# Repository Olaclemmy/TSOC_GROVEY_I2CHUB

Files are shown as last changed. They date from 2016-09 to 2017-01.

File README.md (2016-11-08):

# TSOC_GROVEY_I2CHUB
**TSOC_GROVEY_I2CHUB** is a four(4) port I2C Hub/Switch board, an Embedded Module for thingSoC.

The **TSOC_GROVEY_I2CHUB** can operate at either 3.3V or 5V, and can also level translate 3.3V processor I2C bus to 5V peripherals when needed.

The **TSOC_GROVEY_I2CHUB** allows you to connect [thingSoC](http://thingsoc.github.io/), [Mikrobus](http://www.mikroe.com/mikrobus/), 
and/or [Grove System](http://www.seeedstudio.com/blog/2016/03/09/tutorial-intro-to-grove-connectors-for-arduinoraspberry-pi-projects/) 
Modules all at the same time, with any processor module.
This gives you maximum flexiblity for sensor and actuator selection, and reuse. 

The thingSoC "Grovey Series" was designed as "Everyday Electronics", a no-frills, low cost, approach to modular embedded product design.
thingSoC boards are similar in size to most break-out-boards (BOBs), but feature a standardized stacking pinout, as well as an I2C metadata store (EEPROM)
to indicate what peripherals are installed.

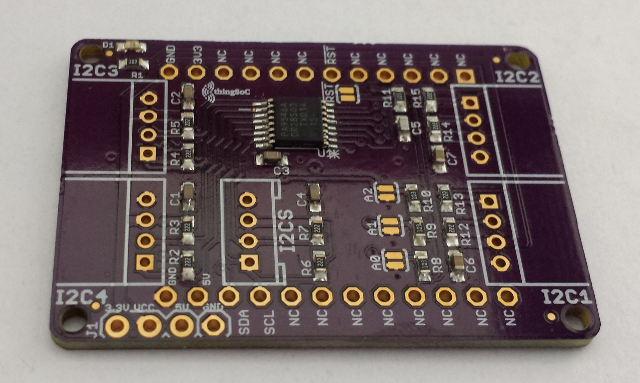
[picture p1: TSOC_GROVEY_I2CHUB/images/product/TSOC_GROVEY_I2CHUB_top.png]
thingSoC GROVEY_I2CHUB
[TSOC_GROVEY_I2CHUB](https://github.com/thingSoC/TSOC_GROVEY_I2CHUB/)

---------------------------------------

In this example, we use the [Grovey_I2CHUB](https://github.com/thingSoC/TSOC_GROVEY_I2CHUB) with the [Teensy3.x](https://www.pjrc.com/teensy/index.html) to support a Grove 16x2 LCD panel.
Since the Grove 16x2 LCD panel is a 5V peripheral, the [Grovey_I2CHUB](https://github.com/thingSoC/TSOC_GROVEY_I2CHUB) performs the voltage level translation
necessary to go from the 3.3V micro-processor to the 5V LCD controller. 

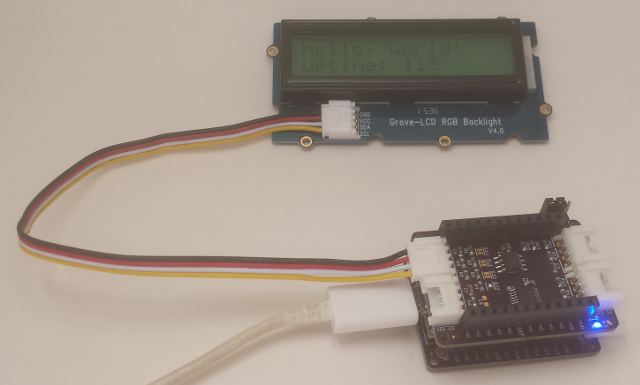
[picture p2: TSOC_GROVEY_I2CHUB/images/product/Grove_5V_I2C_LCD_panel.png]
thingSoC GROVEY_I2CHUB
[TSOC_GROVEY_I2CHUB](https://github.com/thingSoC/TSOC_GROVEY_I2CHUB/)

* [thingSoC Compliant Module](http://www.thingsoc.com)
* [Mikrobus Compatible Module](http://www.mikroe.com/mikrobus/) 
* 5V Nominal Power Input
* 5V or 3.3V Operation
* Supports four (4) separate I2C busses 

---------------------------------------
## Example Uses

* Any time you want to connect four (4) of the same sensor, using the same I2C address, then you need an I2C Hub/Switch.
* Adds four (4) I2C ports to any [thingSoC](http://thingsoc.github.io/), [Mikrobus](http://www.mikroe.com/mikrobus/), 
and/or [Grove System](http://www.seeedstudio.com/blog/2016/03/09/tutorial-intro-to-grove-connectors-for-arduinoraspberry-pi-projects/) peripherals.

---------------------------------------
## 3D Model (Sketchup)

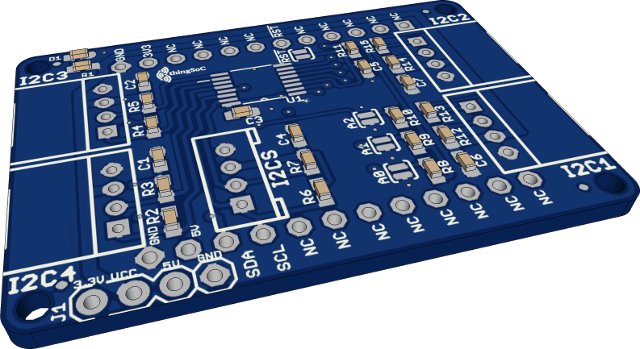
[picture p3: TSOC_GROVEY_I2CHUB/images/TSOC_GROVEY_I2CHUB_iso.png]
thingSoC TSOC_GROVEY_I2CHUB


---------------------------------------
## Project Status

* 09/02/2016 : Revision 2.0 Release for PCB fab

## Revision 2.0 Notes: ##

* Add Ground Strap, remove FM24V10 FRAM, add GROVE I2C Slave connector slot.

## Revision 2.1 Notes: ##

* Remove Ground Strap, it was confusing for power configuration and assembly.
* Prototype testing complete, Production Ready

---------------------------------------

## Documentation Index <a name="documentation_index"/>

[Quick Start Guide](https://github.com/thingSoC/TSOC_GROVEY_I2CHUB/blob/master/TSOC_GROVEY_I2CHUB/docs/QuickStart.md)

[User Guide](https://github.com/thingSoC/TSOC_GROVEY_I2CHUB/blob/master/TSOC_GROVEY_I2CHUB/docs/UserGuide.md)

[Theory of Operation](https://github.com/thingSoC/TSOC_GROVEY_I2CHUB/blob/master/TSOC_GROVEY_I2CHUB/docs/TheoryOfOperation.md)

[thingSoC Organization Website](http://thingSoC.github.io)

[thingSoC FAQ - Frequently Asked Questions](http://thingsoc.github.io/support/faq.html)

---------------------------------------

[  
*thingSoC*](http://thingsoc.github.io)

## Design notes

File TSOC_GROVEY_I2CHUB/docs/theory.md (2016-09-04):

# TSOC_GROVEY_I2CHUB Theory of Operation

***TSOC_GROVEY_I2CHUB** is a self contained, Embedded Wi-Fi Module, with integated Li-Po battery control and charging.

**TSOC_GROVEY_I2CHUB** includes an ESP8266 Wi-Fi module, 
along with an [PCA8575 I/O Expander](http://www.nxp.com/documents/data_sheet/PCA8575.pdf) 
to provide an additional 16 Input/Output pins for the thingSoC Standard Socket,
and a Color RGB LED for USER status, with additonal, individual LEDS for Battery Charger Status and USB Status.

[thingSoC TSOC_GROVEY_I2CHUB  
*TSOC_GROVEY_I2CHUB*](https://github.com/PatternAgents/TSOC_GROVEY_I2CHUB/)

* [Supported by the Arduino IDE](https://www.arduino.cc/) 
* [thingSoC Compliant Module](http://www.thingsoc.com)
* [Mikrobus Compatible Module](http://www.mikroe.com/mikrobus/) 

---------------------------------------

## Theory of Operation <a name="theory_index"/>

The **TSOC_GROVEY_I2CHUB** supports a single "thingSoC" socket with 3.3 Volt Level signaling.

### Page A : USB Connector, Battery Connector and Power Supply<a name="PAGEA"/>

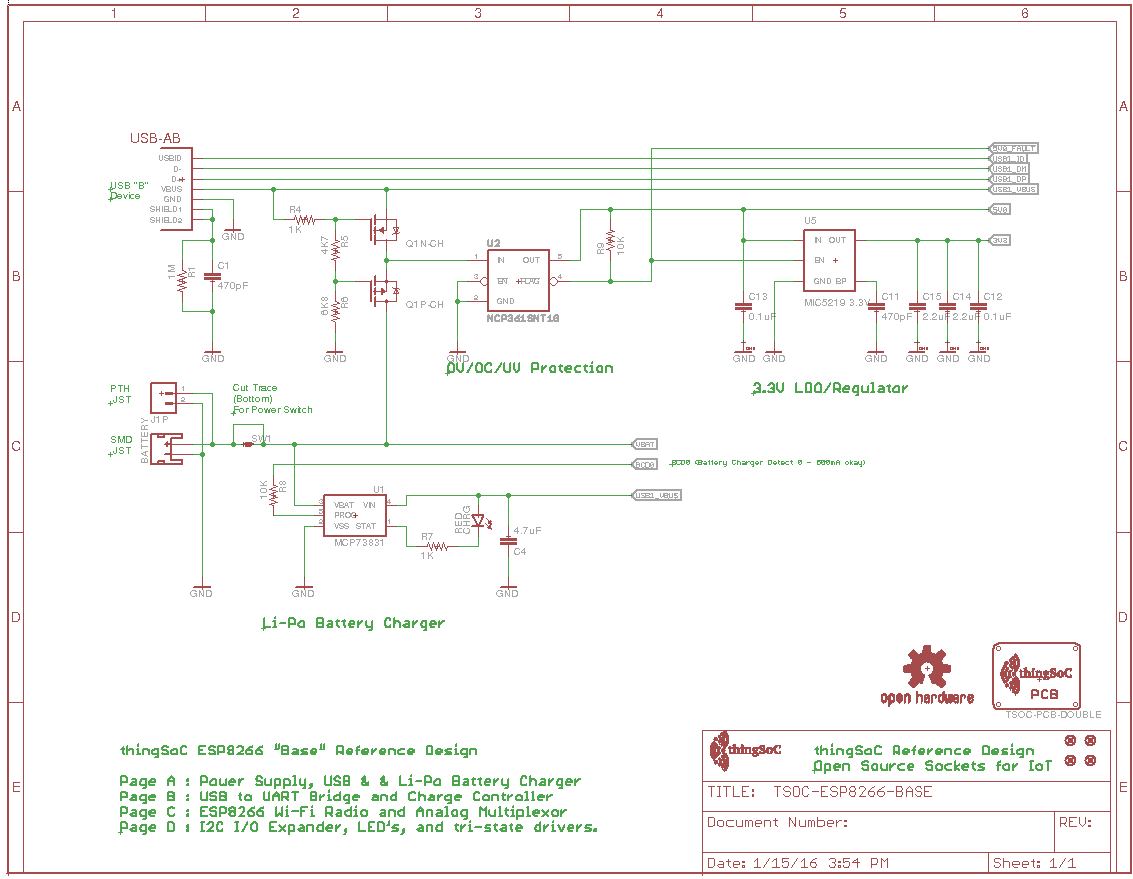
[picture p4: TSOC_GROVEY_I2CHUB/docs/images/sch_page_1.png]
Schematic Page A


Limitations: 

### Page B : USB to UART Bridge Controller <a name="PAGEB"/>

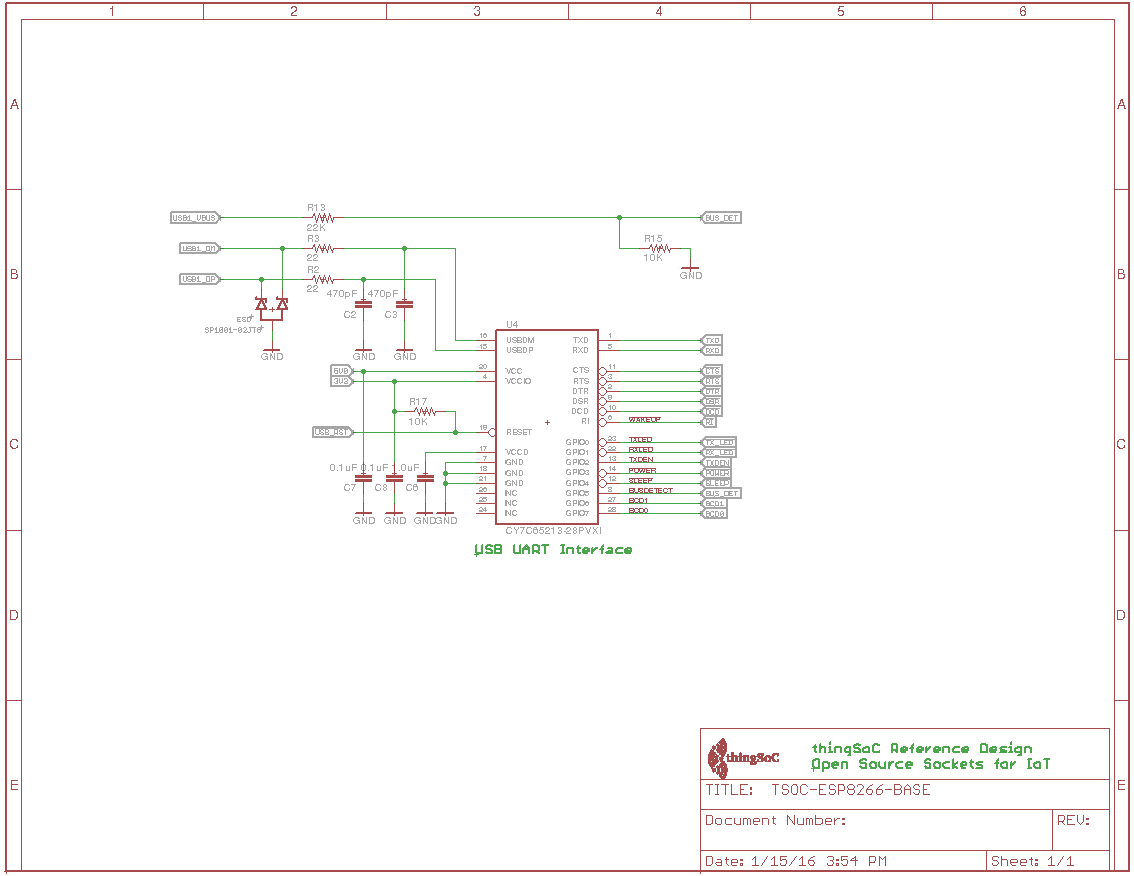
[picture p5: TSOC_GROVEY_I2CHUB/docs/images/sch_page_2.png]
Schematic Page B


### Page C <a name="PAGEC"/>

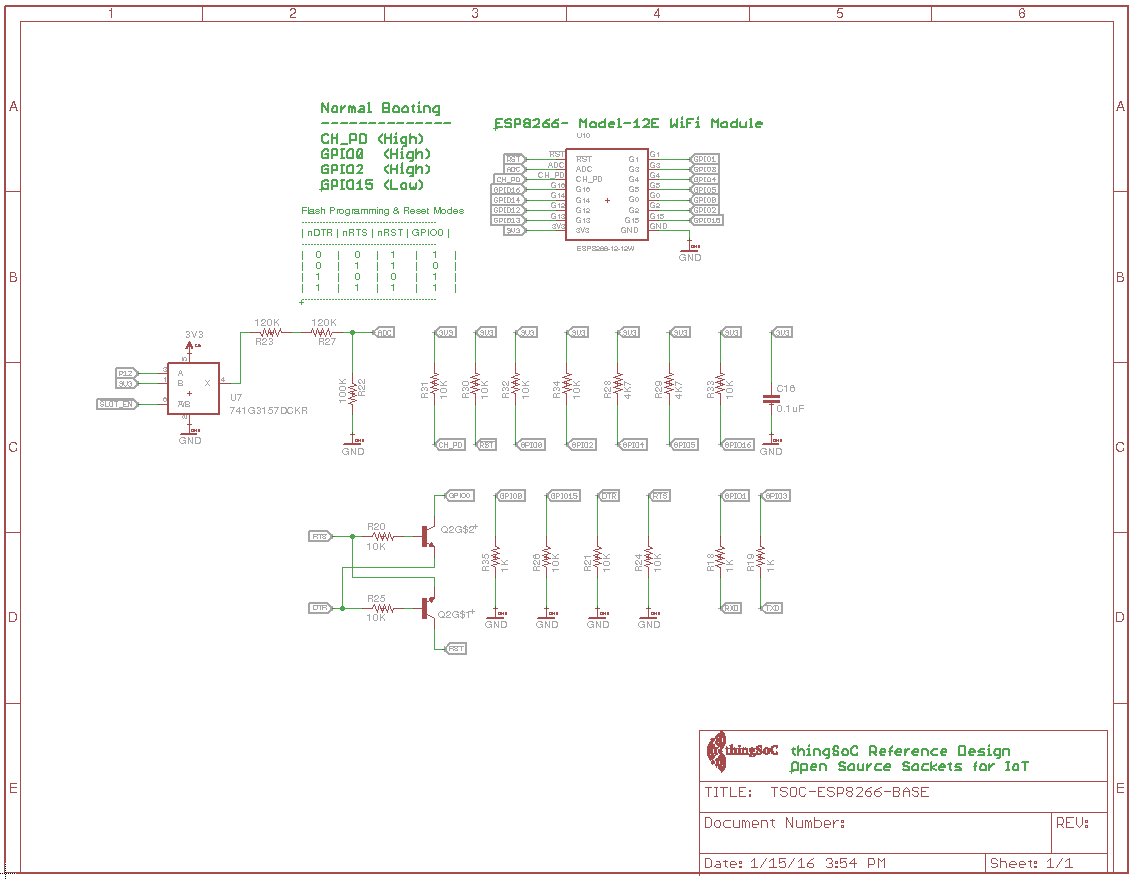
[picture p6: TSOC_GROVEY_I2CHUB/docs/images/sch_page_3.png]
Schematic Page C


### Page D <a name="PAGED"/>

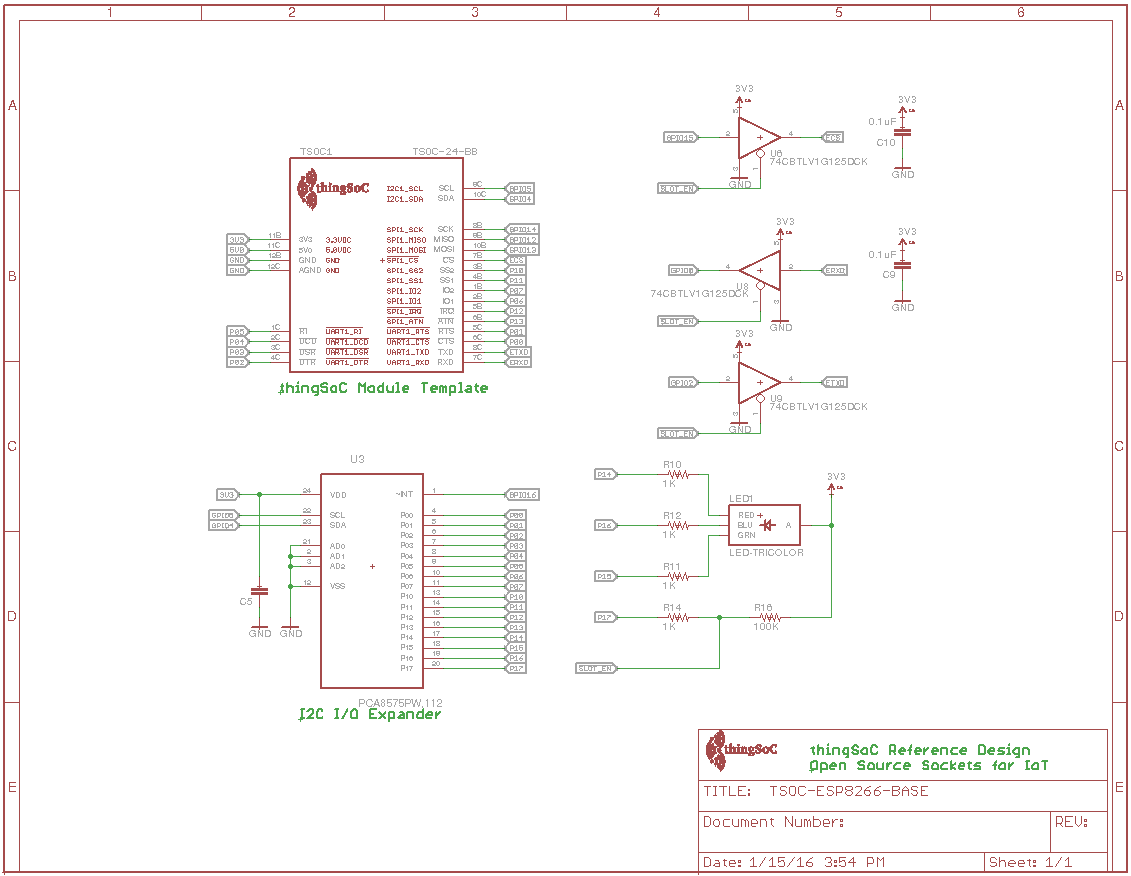
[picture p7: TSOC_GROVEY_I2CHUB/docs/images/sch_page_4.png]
Schematic Page D


---------------------------------------

## Documentation Index <a name="documentation_index"/>

[TSOC_GROVEY_I2CHUB Quick Start Guide](https://github.com/PatternAgents/TSOC_GROVEY_I2CHUB/blob/master/TSOC_GROVEY_I2CHUB/docs/qsg.md)

[TSOC_GROVEY_I2CHUB User Guide](https://github.com/PatternAgents/TSOC_GROVEY_I2CHUB/blob/master/TSOC_GROVEY_I2CHUB/docs/ug.md)

[TSOC_GROVEY_I2CHUB Theory of Operation](https://github.com/PatternAgents/TSOC_GROVEY_I2CHUB/blob/master/TSOC_GROVEY_I2CHUB/docs/theory.md)

[thingSoC Organization Website](http://thingSoC.github.io)

[thingSoC FAQ - Frequently Asked Questions](http://thingsoc.github.io/support/faq.html)

[ESP8266 Community](https://github.com/esp8266/Arduino)

---------------------------------------

[  
*thingSoC*](http://thingsoc.github.io)

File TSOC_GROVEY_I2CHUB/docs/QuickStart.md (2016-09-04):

# TSOC_GROVEY_I2CHUB Quick Start Guide

Welcome! <br>
The **TSOC_GROVEY_I2CHUB**  Quick Start Guide is a series of quick steps to try out your new board.

---------------------------------------

## Quick Start Guide <a name="quickstartguide_index"/>

1. Plug the **TSOC_GROVEY_I2CHUB** into another thingSoC board, such as the Teensy3x or Grovey_WiFi
2. Plug an I2C Peripheral into the **TSOC_GROVEY_I2CHUB** and note which port number (there are four ports).
3. Open the Arduino IDE and Select "File -> Examples -> TSOC_GROVEY_I2CHUB -> Port X  
   where X is the Port number that your installed your peripheral into
4. Follow the instructions on your screen to configure the TSOC_GROVEY_I2CHUB for your application.

[thingSoC GROVEY_I2CHUBTSOC_GROVEY_I2CHUB](https://github.com/thingSoC/TSOC_GROVEY_I2CHUB/)

---------------------------------------

## Documentation Index <a name="documentation_index"/>

[TSOC_GROVEY_I2CHUB Quick Start Guide](https://github.com/thingSoC/TSOC_GROVEY_I2CHUB/blob/master/TSOC_GROVEY_I2CHUB/docs/QuickStart.md)

[TSOC_GROVEY_I2CHUB User Guide](https://github.com/thingSoC/TSOC_GROVEY_I2CHUB/blob/master/TSOC_GROVEY_I2CHUB/docs/UserGuide.md)

[TSOC_GROVEY_I2CHUB Theory of Operation](https://github.com/thingSoC/TSOC_GROVEY_I2CHUB/blob/master/TSOC_GROVEY_I2CHUB/docs/TheoryOfOperation.md)

[thingSoC Organization Website](http://thingSoC.github.io)

[thingSoC FAQ - Frequently Asked Questions](http://thingsoc.github.io/support/faq.html)

---------------------------------------

[  
*thingSoC*](http://thingsoc.github.io)

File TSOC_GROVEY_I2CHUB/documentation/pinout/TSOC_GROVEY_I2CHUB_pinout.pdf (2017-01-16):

Sheet1

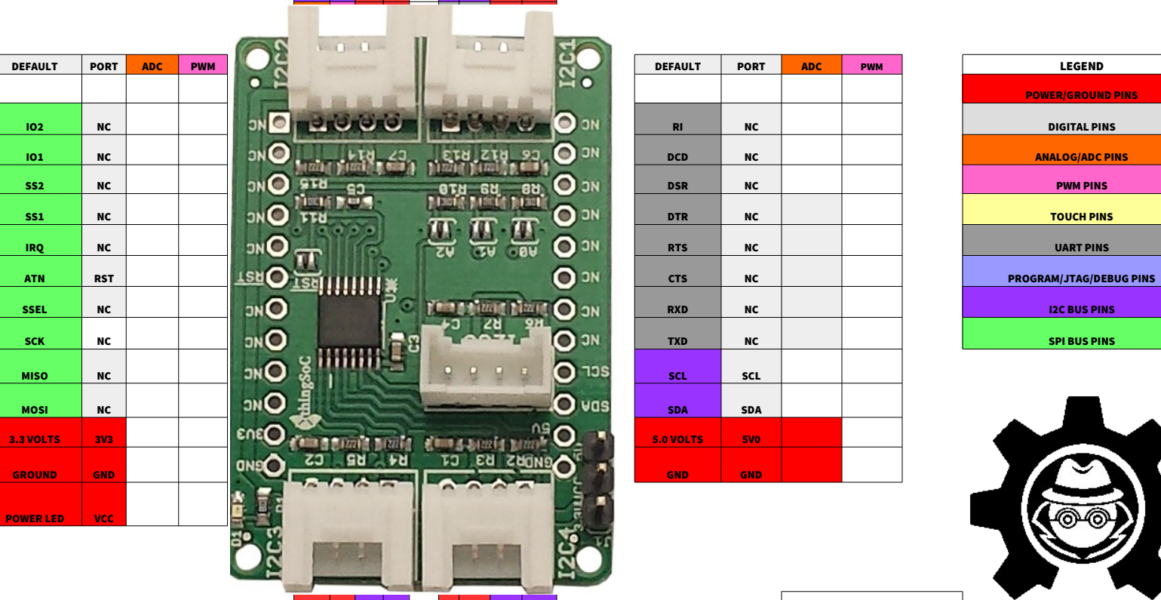
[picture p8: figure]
DIGITAL PINS; DCD; ANALOG/ADC PINS; DSR; PWM PINS; DTR; TOUCH PINS; IRQ; RTS; UART PINS; ATN; RST; CTS; PROGRAM/JTAG/DEBUG PINS; SSEL; RXD; I2C BUS PINS; SCK; TXD; SPI BUS PINS; MISO; SCL; MOSI; SDA; 3.3 VOLTS; 5.0 VOLTS; GROUND; GND; POWER LED; VCC

Page 1

DEFAULT | PORT | ADC | PWM | DEFAULT | PORT | ADC | PWM | LEGEND
| | | | | | | | POWER/GROUND PINS

## PatternAgents

TSOC_GROVEY_I2CHUB

I 2 C 2 | I 2 C 2 | P W R | G N D | I 2 C 1 | I 2 C 1 | P W R | G N D
S D A | S C L | V C C | G N D | S C L | S D A | V C C | G N D

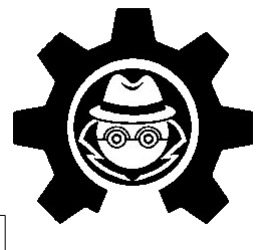
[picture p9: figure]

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
### 4 http://github.com/thingsoc/

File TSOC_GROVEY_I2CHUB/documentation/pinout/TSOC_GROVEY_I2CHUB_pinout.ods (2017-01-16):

 |  |  |  | I2C2 | I2C2 | PWR | GND | I2C1 | I2C1 | PWR | GND
 |  |  |  | SDA | SCL | VCC | GND | SCL | SDA | VCC | GND
DEFAULT | PORT | ADC | PWM |  |  |  |  |  |  |  |  | DEFAULT | PORT | ADC | PWM | LEGEND
 |  |  |  |  |  |  |  |  |  |  |  |  |  |  |  | POWER/GROUND PINS
IO2 | NC |  |  |  |  |  |  |  |  |  |  | RI | NC |  |  | DIGITAL PINS
IO1 | NC |  |  |  |  |  |  |  |  |  |  | DCD | NC |  |  | ANALOG/ADC PINS
SS2 | NC |  |  |  |  |  |  |  |  |  |  | DSR | NC |  |  | PWM PINS
SS1 | NC |  |  |  |  |  |  |  |  |  |  | DTR | NC |  |  | TOUCH PINS
IRQ | NC |  |  |  |  |  |  |  |  |  |  | RTS | NC |  |  | UART PINS
ATN | RST |  |  |  |  |  |  |  |  |  |  | CTS | NC |  |  | PROGRAM/JTAG/DEBUG PINS
SSEL | NC |  |  |  |  |  |  |  |  |  |  | RXD | NC |  |  | I2C BUS PINS
SCK | NC |  |  |  |  |  |  |  |  |  |  | TXD | NC |  |  | SPI BUS PINS
MISO | NC |  |  |  |  |  |  |  |  |  |  | SCL | SCL
MOSI | NC |  |  |  |  |  |  |  |  |  |  | SDA | SDA
3.3 VOLTS | 3V3 |  |  |  |  |  |  |  |  |  |  | 5.0 VOLTS | 5V0
GROUND | GND |  |  |  |  |  |  |  |  |  |  | GND | GND
POWER LED | VCC
 |  |  |  | GND | VCC | SDA | SCL | GND | VCC | SDA | SCL |  |  |  | PatternAgents
 |  |  |  | GND | PWR | I2C3 | I2C3 | GND | PWR | I2C4 | I2C4 |  |  |  | http://github.com/thingsoc/
 |  |  |  |  |  |  |  |  |  |  |  |  |  |  | TSOC_GROVEY_I2CHUB

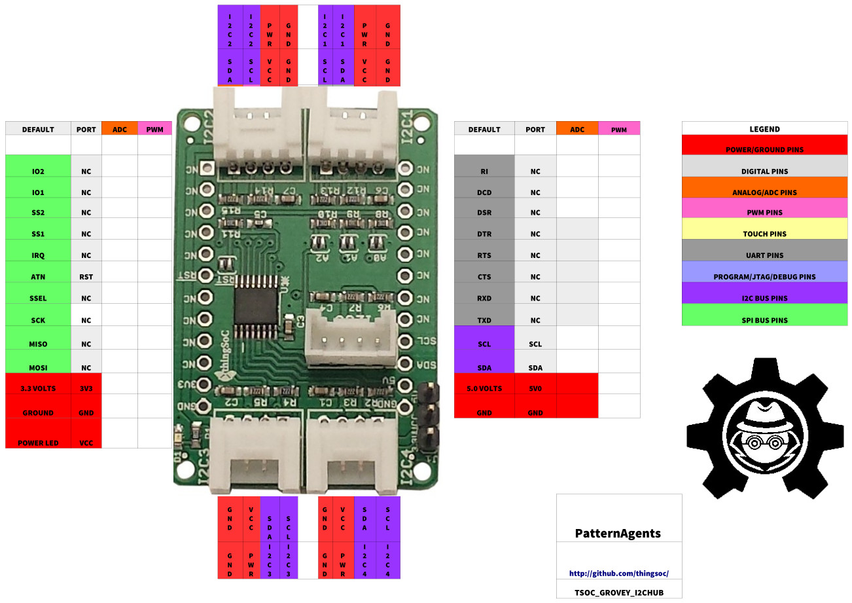
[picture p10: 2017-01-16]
TSOC_GROVEY_I2CHUB/documentation/pinout/TSOC_GROVEY_I2CHUB_pinout.jpg

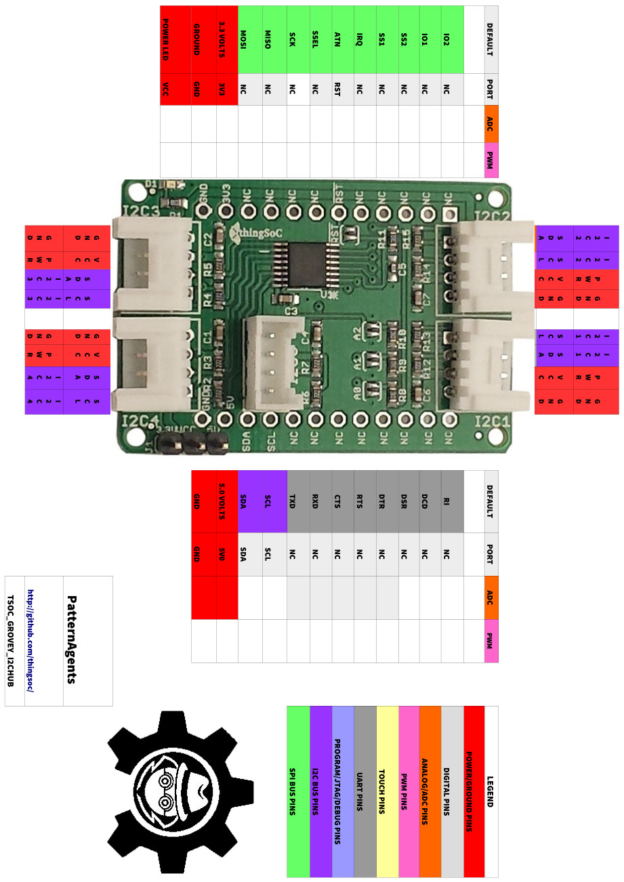
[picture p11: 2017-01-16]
TSOC_GROVEY_I2CHUB/documentation/pinout/TSOC_GROVEY_I2CHUB_pinout_long.jpg

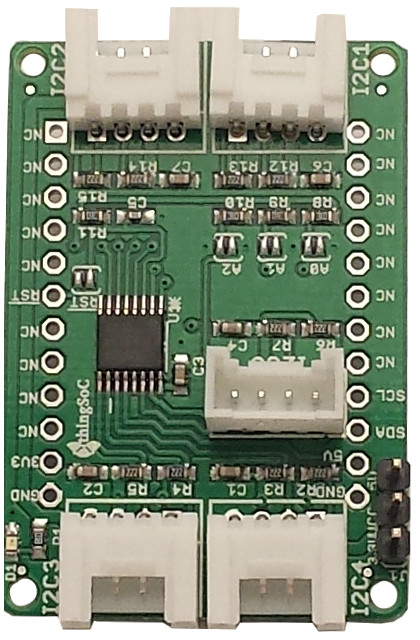
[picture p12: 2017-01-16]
TSOC_GROVEY_I2CHUB/images/product/TSOC_GROVEY_I2CHUB_topvert.jpg

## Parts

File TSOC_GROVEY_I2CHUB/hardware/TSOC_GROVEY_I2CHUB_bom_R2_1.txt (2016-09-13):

Partlist exported from U:/PatternAgents/eagle/TSOC_Modules/TSOC_GROVEY_I2CHUB/TSOC_GROVEY_I2CHUB/TSOC_GROVEY_I2CHUB.sch Revison 2.0 at 9/2/2016 12:30:56 PM

Part  Value             Device                          Package           Description                           
D1    RED               LED0603                         LED-0603          LEDs                                  
C1    0.1uF             CAP0603-CAP                     0603-CAP          Capacitor                             
C2    0.1uF             CAP0603-CAP                     0603-CAP          Capacitor                             
C3    0.1uF             CAP0603-CAP                     0603-CAP          Capacitor                             
C4    0.1uF             CAP0603-CAP                     0603-CAP          Capacitor                             
C5    470pF             CAP0603-CAP                     0603-CAP          Capacitor                             
C6    0.1uF             CAP0603-CAP                     0603-CAP          Capacitor                             
C7    0.1uF             CAP0603-CAP                     0603-CAP          Capacitor                             
I2C1  4P-2.0-90D        GROVE-CONNECTOR-DIP-90D(4P-2.0) HW4-2.0-90D       320110034                             
I2C2  4P-2.0-90D        GROVE-CONNECTOR-DIP-90D(4P-2.0) HW4-2.0-90D       320110034                             
I2C3  4P-2.0-90D        GROVE-CONNECTOR-DIP-90D(4P-2.0) HW4-2.0-90D       320110034                             
I2C4  4P-2.0-90D        GROVE-CONNECTOR-DIP-90D(4P-2.0) HW4-2.0-90D       320110034                             
R1    1K                RESISTOR_SFE0603-RES            0603-RES          Resistor                              
R2    2k2               RESISTOR0603-RES                0603-RES          Resistor                              
R3    2k2               RESISTOR0603-RES                0603-RES          Resistor                              
R4    2k2               RESISTOR0603-RES                0603-RES          Resistor                              
R5    2k2               RESISTOR0603-RES                0603-RES          Resistor                              
R6    2k2               RESISTOR0603-RES                0603-RES          Resistor                              
R7    2k2               RESISTOR0603-RES                0603-RES          Resistor                              
R8    10K               RESISTOR0603-RES                0603-RES          Resistor                              
R9    10K               RESISTOR0603-RES                0603-RES          Resistor                              
R10   10K               RESISTOR0603-RES                0603-RES          Resistor                              
R11   10k               RESISTOR0603-RES                0603-RES          Resistor                              
R12   2k2               RESISTOR0603-RES                0603-RES          Resistor                              
R13   2k2               RESISTOR0603-RES                0603-RES          Resistor                              
R14   2k2               RESISTOR0603-RES                0603-RES          Resistor                              
R15   2k2               RESISTOR0603-RES                0603-RES          Resistor                              
U1    PCA9546A          PCA9546A                        SOP65P640X110-16N 4-channel I2C-bus switch with reset   
J1    NO                JMP-3-NO-PTH                    JMP-3-NO-PTH-2.54 Three Terminal Jumper
JMP1  Jumper            2 Pin Jumper                    2 Pin Jumper      Installed on J1-1 to J1-2 (3.3V)

Do Not Populate
--------------------------------------------------------------------------------------------
GND                     M01PTH                          1X01              Ground Strap  
I2CS  4P-2.0            GROVE-CONNECTOR-DIP(4P-2.0)     HW4-2.0           320110033                             
!RST  NO                JMP-2-NO                        JMP-2-NO          Basic Jumper - Normally Open          
A0    NO                JMP-2-NO                        JMP-2-NO          Basic Jumper - Normally Open          
A1    NO                JMP-2-NO                        JMP-2-NO          Basic Jumper - Normally Open          
A2    NO                JMP-2-NO                        JMP-2-NO          Basic Jumper - Normally Open

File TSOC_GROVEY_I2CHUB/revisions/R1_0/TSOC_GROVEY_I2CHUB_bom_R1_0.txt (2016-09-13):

Partlist exported from U:/PatternAgents/eagle/TSOC_Modules/TSOC_GROVEY_I2CHUB/TSOC_GROVEY_I2CHUB/TSOC_GROVEY_I2CHUB.sch at 8/26/2016 2:21:03 PM

Qty Value             Device                          Package           Parts                                        Description
1                     EEPROM_I2C_SOIC8_GENERIC        SOIC8_150MIL      U2                                           Note: The same pinout is used 
5                     JMP-2-NO                        JMP-2-NO          SJ0, SJ1, SJ2, SJ3, SJ4                      Basic Jumper - Normally Open
1                     JMP-3-NO-PTH                    JMP-3-NO-PTH-2.54 J1                                           Three Terminal Jumper - Normally Op
1                     LED0603                         LED-0603          D1                                           LEDs
3                     RESISTOR0603-RES                0603-RES          R1, R2, R3                                   Resistor  
6   0.1uF             CAP0603-CAP                     0603-CAP          C1, C2, C4, C5, C6, C7                       Capacitor     
2   10k               RESISTOR0603-RES                0603-RES          R4, R5                                       Resistor
1   1K                RESISTOR_SFE0603-RES            0603-RES          R16                                          Resistor          
10  2k2               RESISTOR0603-RES                0603-RES          R6, R7, R8, R9, R10, R11, R12, R13, R14, R15 Resistor    
1   470nF             CAP0603-CAP                     0603-CAP          C3                                           Capacitor 
4   4P-2.0-90D        GROVE-CONNECTOR-DIP-90D(4P-2.0) HW4-2.0-90D       J1_I2C, J2_I2C, J3_I2C, J4_I2C               320110034                          
1   PCA9546A          PCA9546A                        SOP65P640X110-16N U1                                           4-channel I2C-bus switch with reset

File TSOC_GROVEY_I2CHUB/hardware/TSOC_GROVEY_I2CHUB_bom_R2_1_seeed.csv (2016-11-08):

Part/Designator | Manufacture Part Number/Seeed SKU | Quantity
C1, C2, C3, C4, C6, C7 | 302010138 | 6
R8, R9, R10, R11 | 301010299 | 4
R1 | 301010298 | 1
R2, R3, R4, R5, R6, R7, R12, R13, R14, R15 | 301010124 | 10
C5 | 302010013 | 1
I2C1, I2C2, I2C3, I2C4 | 320110034 | 4
I2CS | "320110033" | 1
J1 | 320020079 | 1
U1 | PCA9546A | 1
D1 | 304090043 | 1

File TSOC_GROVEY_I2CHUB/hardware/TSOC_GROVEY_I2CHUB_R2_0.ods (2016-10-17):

Qty | Value | Device | Package | Parts | Description | BOM | Seeed# | Seeed$ | MPN | OC_FARNELL | OC_NEWARK | PACKAGE | SUPPLIER | VALUE
1 | 1K | RESISTOR_SFE0603-RES | 0603-RES | R1 | Resistor | INCLUDE | 301010291 | $0.01
10 | 2k2 | RESISTOR0603-RES | 0603-RES | R2, R3, R4, R5, R6, R7, R12, R13, R14, R15 | Resistor | INCLUDE | 301010124 | $0.01
4 | 10K | RESISTOR0603-RES | 0603-RES | R8, R9, R10, R11 | Resistor | INCLUDE | 301010293 | $0.01
1 | 470pF | CAP0603-CAP | 0603-CAP | C5 | Capacitor | INCLUDE
6 | 0.1uF | CAP0603-CAP | 0603-CAP | C1, C2, C3, C4, C6, C7 | Capacitor | INCLUDE | 302010138 | $0.01
1 | PCA9546A | PCA9546A | SOP65P640X110-16N | U1 | 4-channel I2C-bus switch with reset | INCLUDE |  |  | PCA9546APW,112 | 1831208 | 70R6610 | TSSOP-16 | NXP
1 | GREEN | LED0603 | LED-0603 | D1 | LEDs | INCLUDE | 304090043 | $0.03130
1 | TSOC-PCB-SINGLE | TSOC-PCB-SINGLE | TSOC-BB-BRD-DIM | PCB | thingSoC PCB Outlines | INCLUDE |  | $4.00
1 |  | M01PTH | 1X01 | GND | Header 1 | EXCLUDE
1 | 4P-2.0 | GROVE-CONNECTOR-DIP(4P-2.0) | HW4-2.0 | I2CS |  | EXCLUDE | 320110033 | $0.15 |  |  |  |  |  | 4P-2.0
4 | 4P-2.0-90D | GROVE-CONNECTOR-DIP-90D(4P-2.0) | HW4-2.0-90D | I2C1, I2C2, I2C3, I2C4 |  | EXCLUDE | 320110034 | $0.15 |  |  |  |  |  | 4P-2.0-90D
4 | NO | JMP-2-NO | JMP-2-NO | !RST, A0, A1, A2 | Basic Jumper - Normally Open | EXCLUDE
1 | NO | JMP-3-NO-PTH | JMP-3-NO-PTH-2.54 | J1 | Three Terminal Jumper - Normally Open | EXCLUDE

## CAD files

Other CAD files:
TSOC_GROVEY_I2CHUB/eagleUp/TSOC_GROVEY_I2CHUB.skp

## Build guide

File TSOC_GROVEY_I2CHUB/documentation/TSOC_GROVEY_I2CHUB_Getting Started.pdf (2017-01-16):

### Welcome to the thingSoC® I2C Hub

The TSOC_GROVEY_I2CHUB is an I2C Switch/Hub, based on the NXP PCA9546A chip, in an Embedded Module format for the new thingSoC, Internet of Things open source hardware standard. Getting Started :
The TSOC_GROVEY_I2CHUB provides four (4) high speed I2C ports for four independent I2C channels. While you could just "daisy-chain" four (4) I2C connections, there are several situations that require a "hub", including :
1. When you need to do 3.3 Volt to 5.0 Volt level conversion.
2. When you have several I2C peripherals that use the same I2C address and you cna't change the addess. The "hub" allows you to select between them.
3. When you want to limit the capacitance of each I2C bus segment. This allows you to run the I2C bus faster than daisy-chaining would allow.
The TSOC_GROVEY_I2CHUB is an open source hardware project from PatternAgents, LLC,
and you are free to download the schematics, layouts, gerbers, BOMs, etc and build your own boards if you wish.

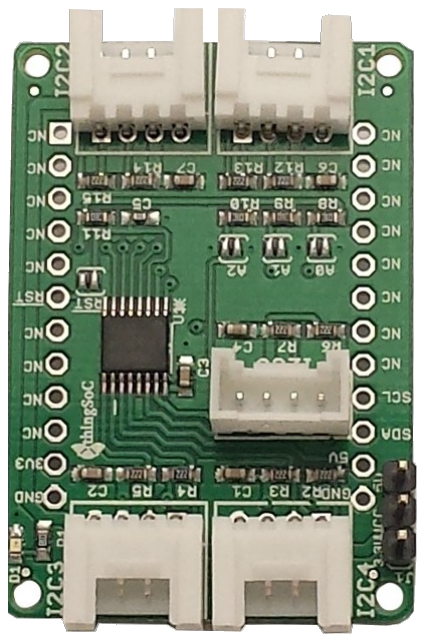
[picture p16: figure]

Safe Handling Precautions :

1) Always remove/unplug all power before inserting or removing peripherals.
2) Always ground yourself by touching a ground point before handling your boards.
3) Use a static safe bag when transporting your TSOC_GROVEY_I2CHUB board.

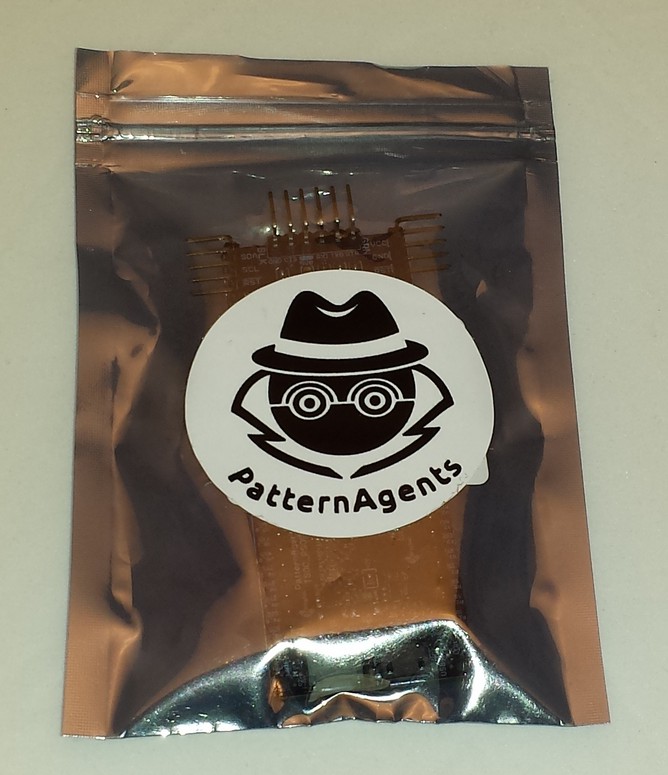
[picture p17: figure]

Adding Grove Peripherals :
The TSOC_GROVEY_I2CHUB board supports Grove peripherals.
1) Grove connectors are polarized, and can only be plugged in one way.

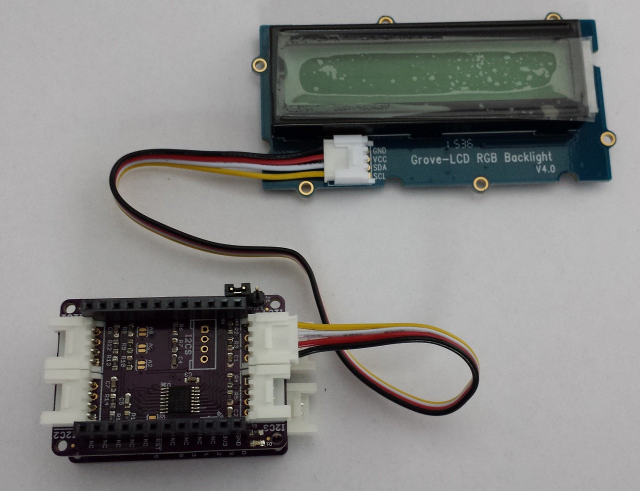
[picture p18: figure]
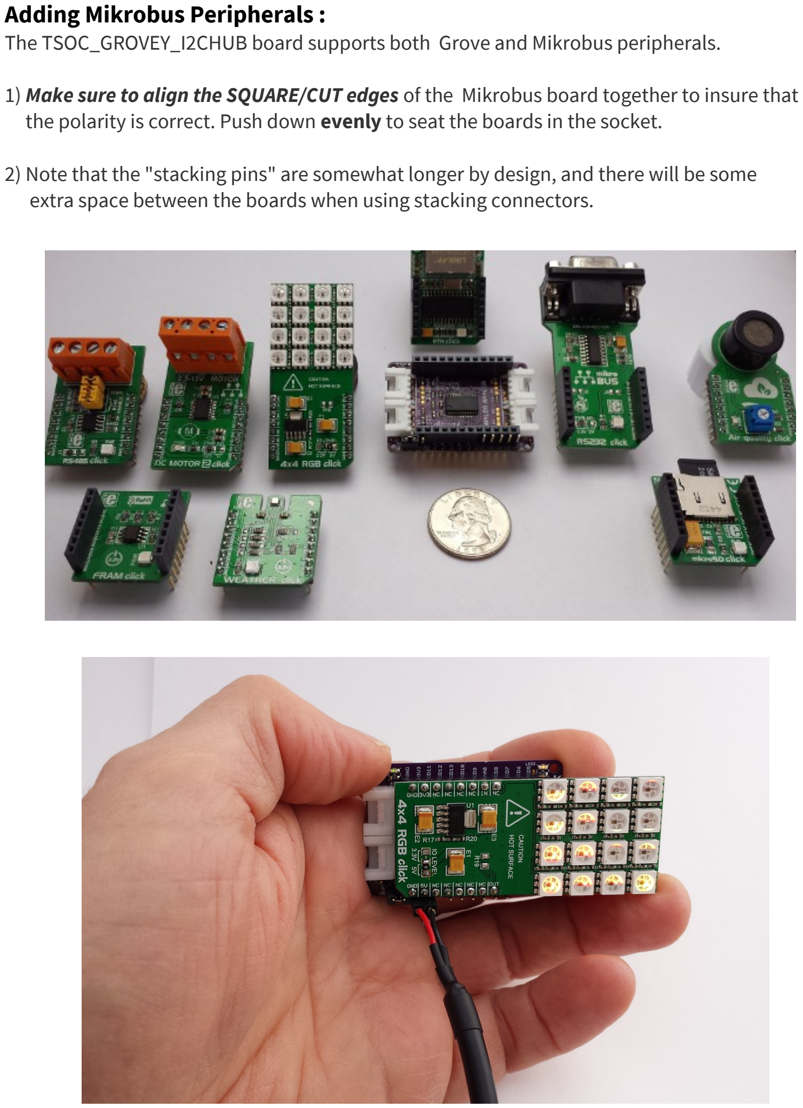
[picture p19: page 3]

Adding Mikrobus Peripherals :
The TSOC_GROVEY_I2CHUB board supports both Grove and Mikrobus peripherals.
1) Make sure to align the SQUARE/CUT edges of the Mikrobus board together to insure that the polarity is correct. Push down evenly to seat the boards in the socket.
2) Note that the "stacking pins" are somewhat longer by design, and there will be some extra space between the boards when using stacking connectors.

### thingSoC® Grovey One Arduino Example :

1) Using Multiple LCD Displays with the TSOC_GROVEY_I2CHUB board

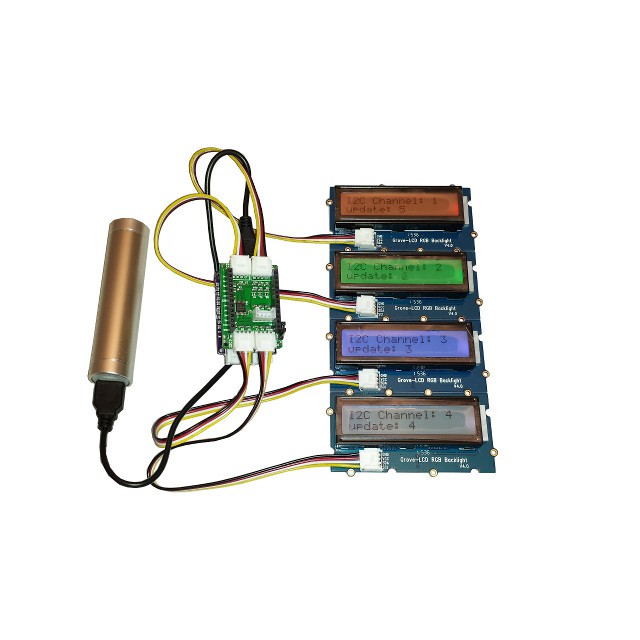
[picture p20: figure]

### For more information and examples :

Complete documentation, including schematics, layouts, gerbers, and Bill of Materials (BOM) are available on the thingSoC website at :

https://github.com/thingSoC/TSOC_GROVEY_I2CHUB/tree/master/TSOC_GROVEY_I2CHUB (https://github.com/thingSoC/TSOC_PSoC4L/tree/master/TSOC_PSoC4L)

There is also a project Wiki available for asking questions and more information at :

https://github.com/thingSoC/TSOC_GROVEY_I2CHUB/wiki (https://github.com/thingSoC/TSOC_PSoC4L/wiki)

thingSoC® Grovey One Features :
The TSOC_GROVEY_I2CHUB is a low cost, embeddable module featuring an NXP PCA9546A device :
- NXP PCA9546A
- 0 Hz to 400KHz I2C Bus Speed
- 3.3 Volt or 5.0 Volt operation
- Optional Active Low Reset Line
- All channels deselected on Power up
- No Glitch switching
- Supports hot insertion
- Low Standby current
- Builtin ESD protection
- I2C (4 Channels)
- Power LEDs
- thingSoC Compliant Module
- Mikrobus Compatible Module (http://www.mikroe.com/mikrobus/)
- Support SeeedStudio Grove Peripherals

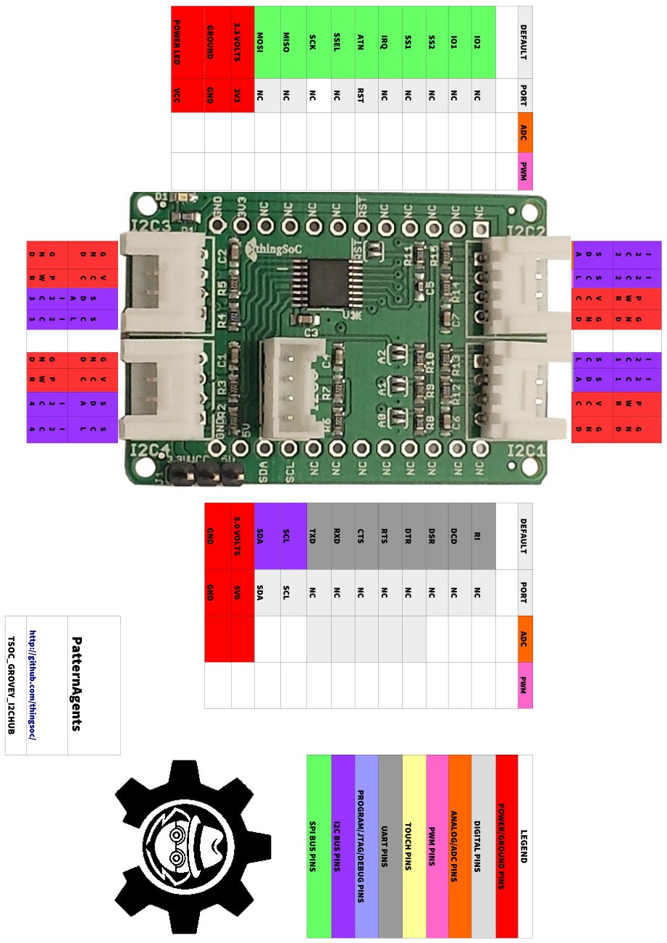
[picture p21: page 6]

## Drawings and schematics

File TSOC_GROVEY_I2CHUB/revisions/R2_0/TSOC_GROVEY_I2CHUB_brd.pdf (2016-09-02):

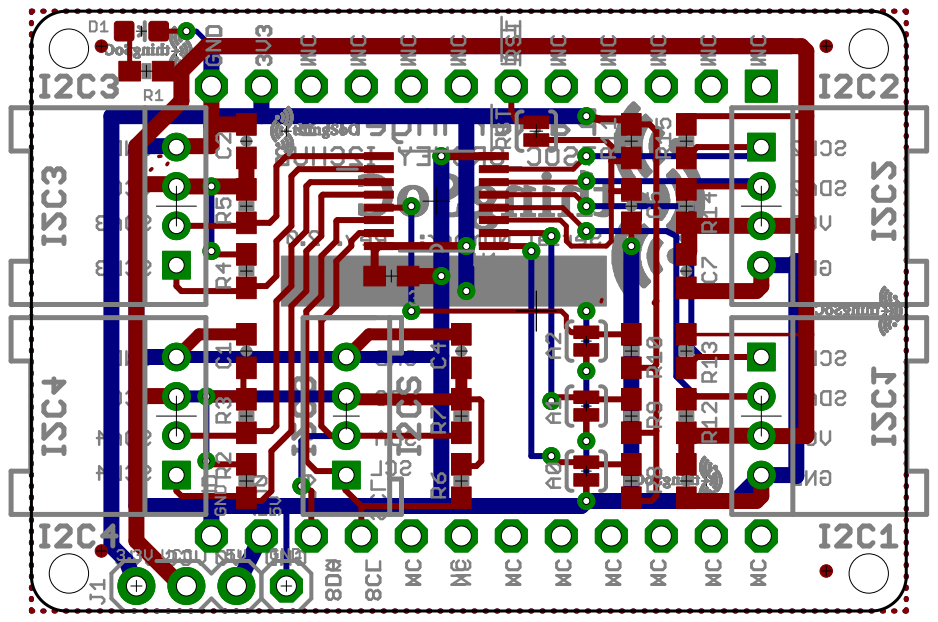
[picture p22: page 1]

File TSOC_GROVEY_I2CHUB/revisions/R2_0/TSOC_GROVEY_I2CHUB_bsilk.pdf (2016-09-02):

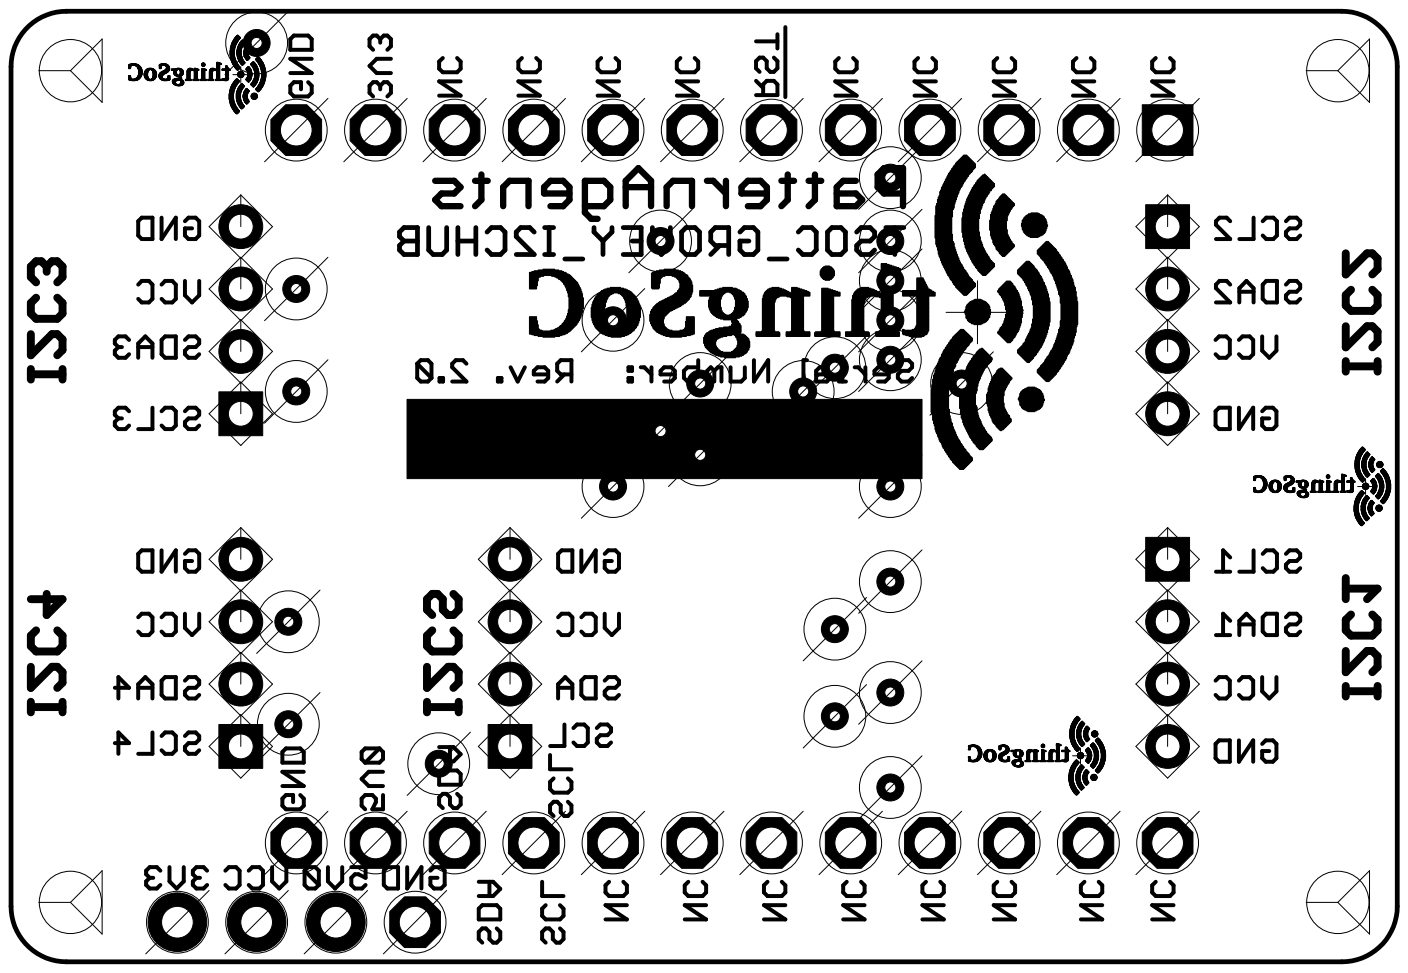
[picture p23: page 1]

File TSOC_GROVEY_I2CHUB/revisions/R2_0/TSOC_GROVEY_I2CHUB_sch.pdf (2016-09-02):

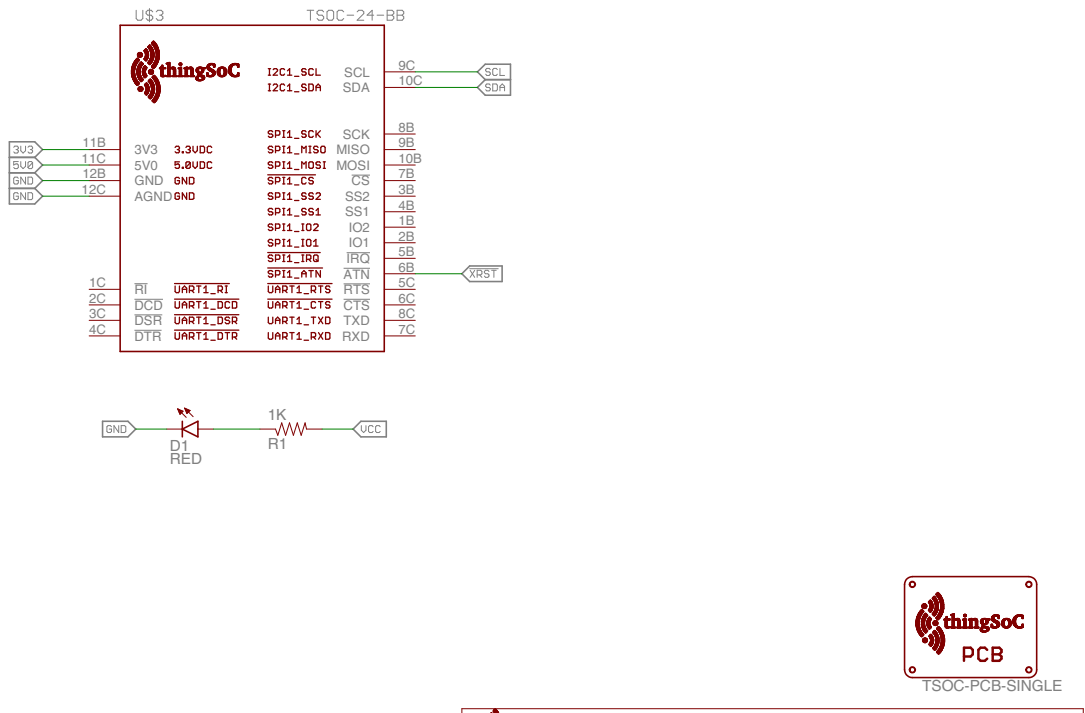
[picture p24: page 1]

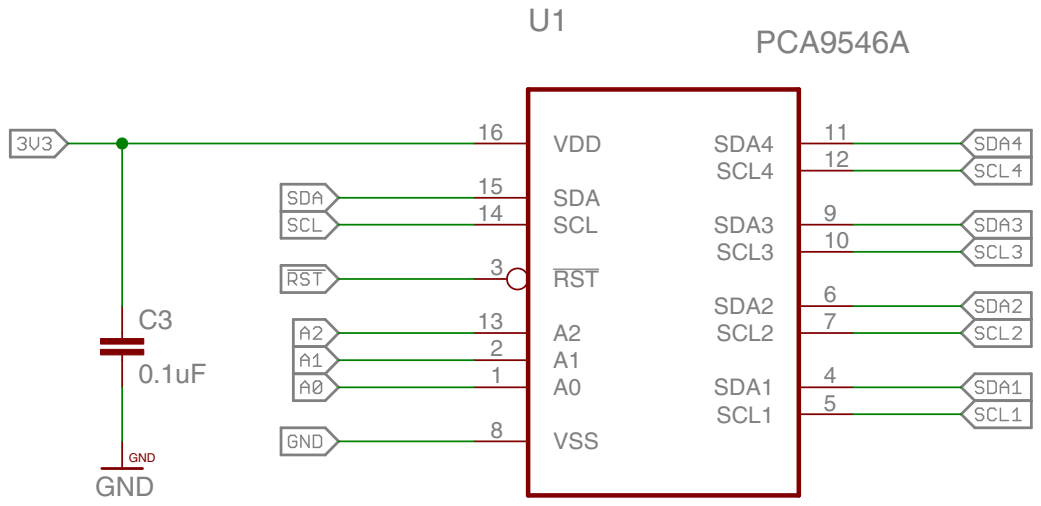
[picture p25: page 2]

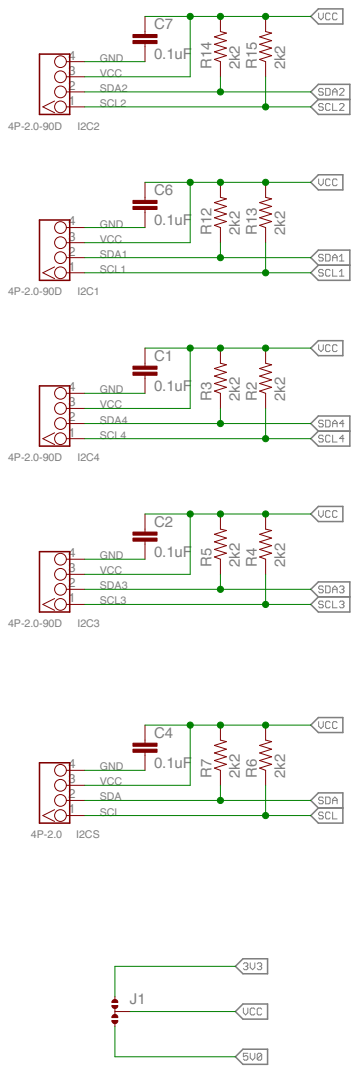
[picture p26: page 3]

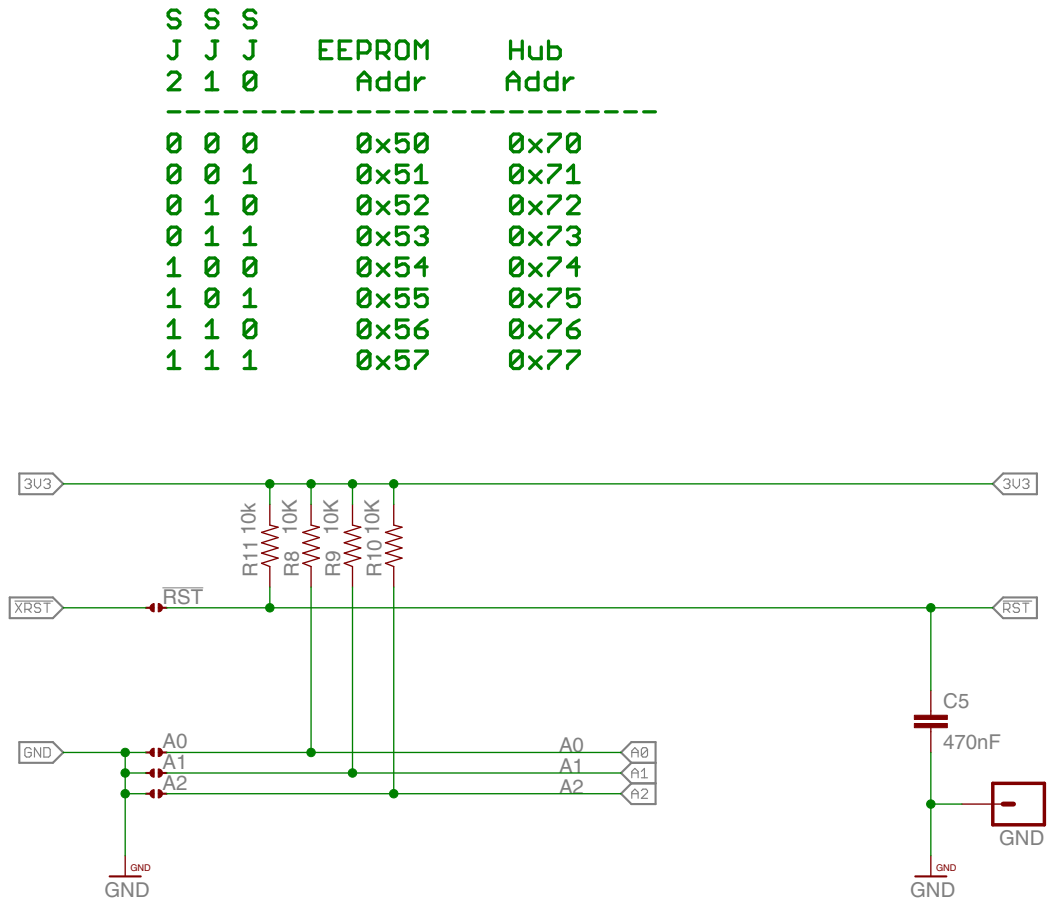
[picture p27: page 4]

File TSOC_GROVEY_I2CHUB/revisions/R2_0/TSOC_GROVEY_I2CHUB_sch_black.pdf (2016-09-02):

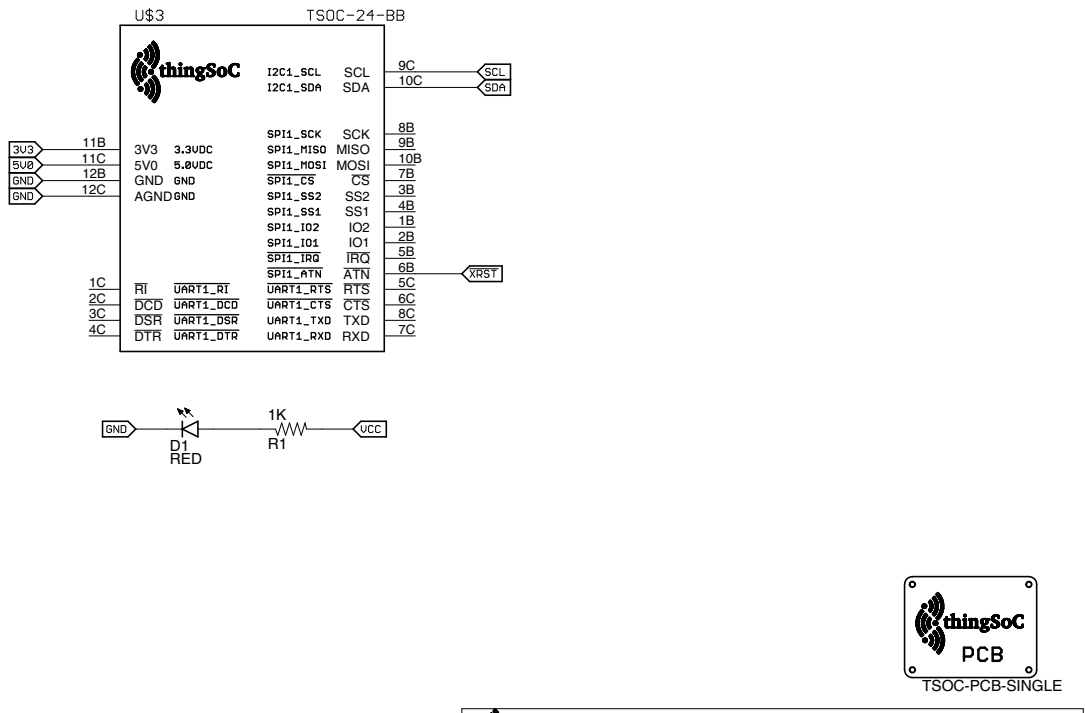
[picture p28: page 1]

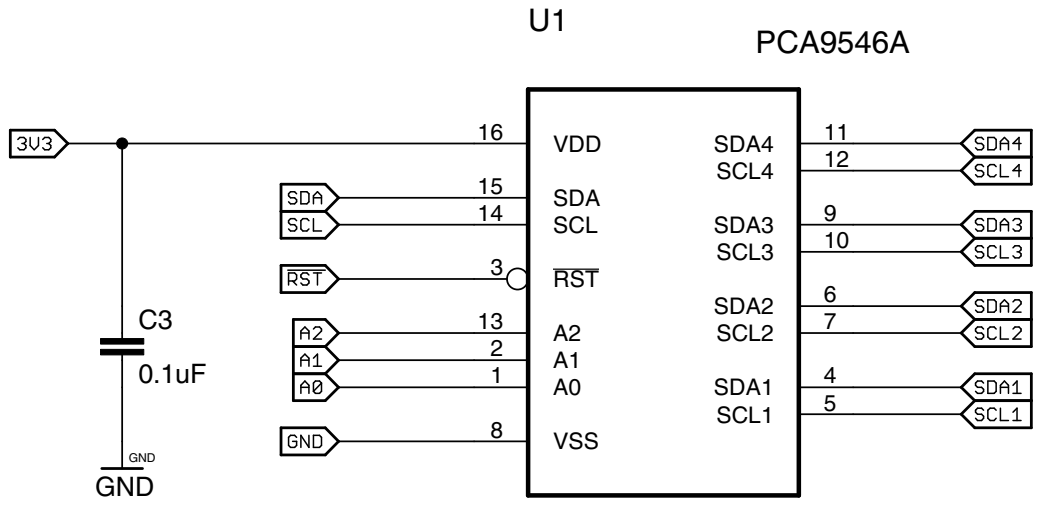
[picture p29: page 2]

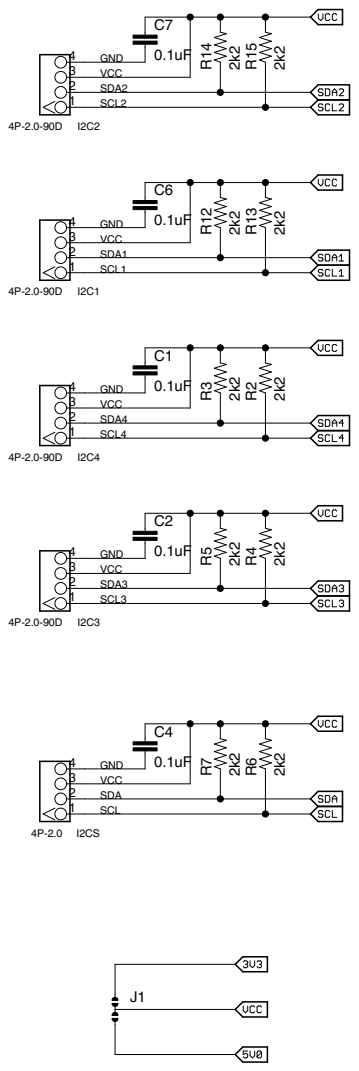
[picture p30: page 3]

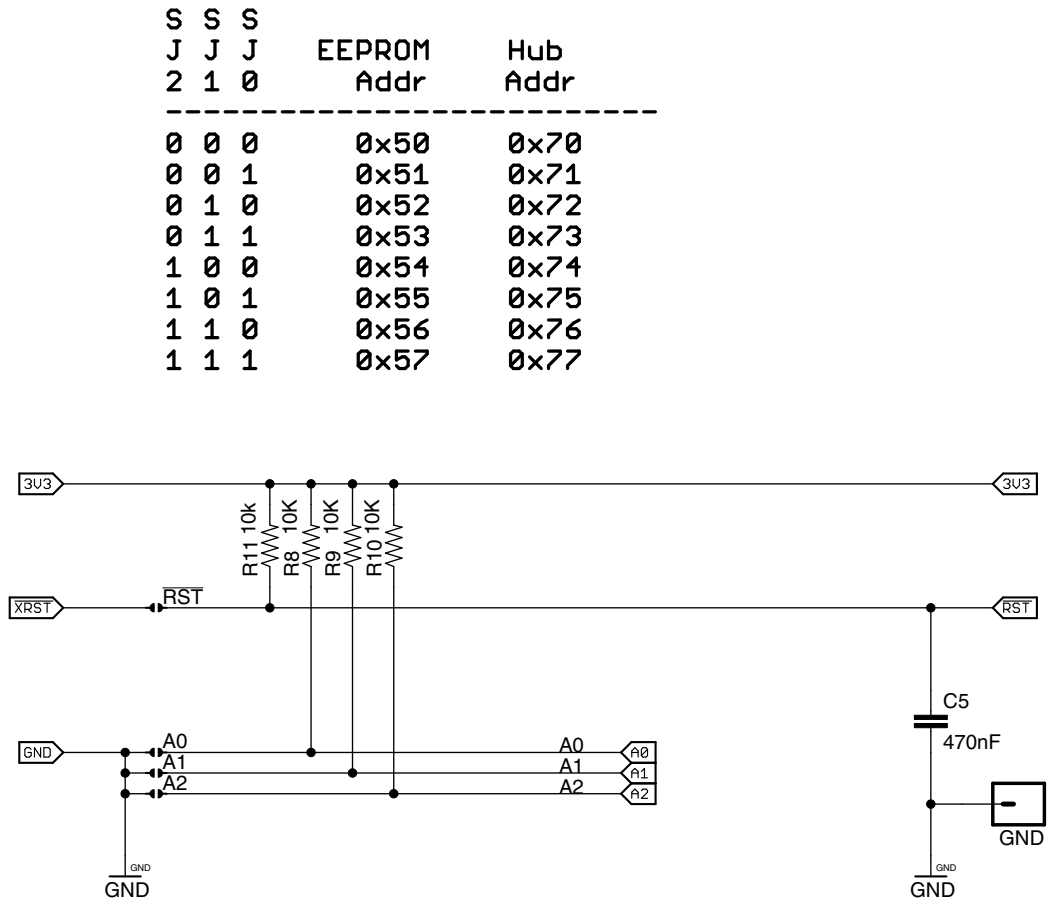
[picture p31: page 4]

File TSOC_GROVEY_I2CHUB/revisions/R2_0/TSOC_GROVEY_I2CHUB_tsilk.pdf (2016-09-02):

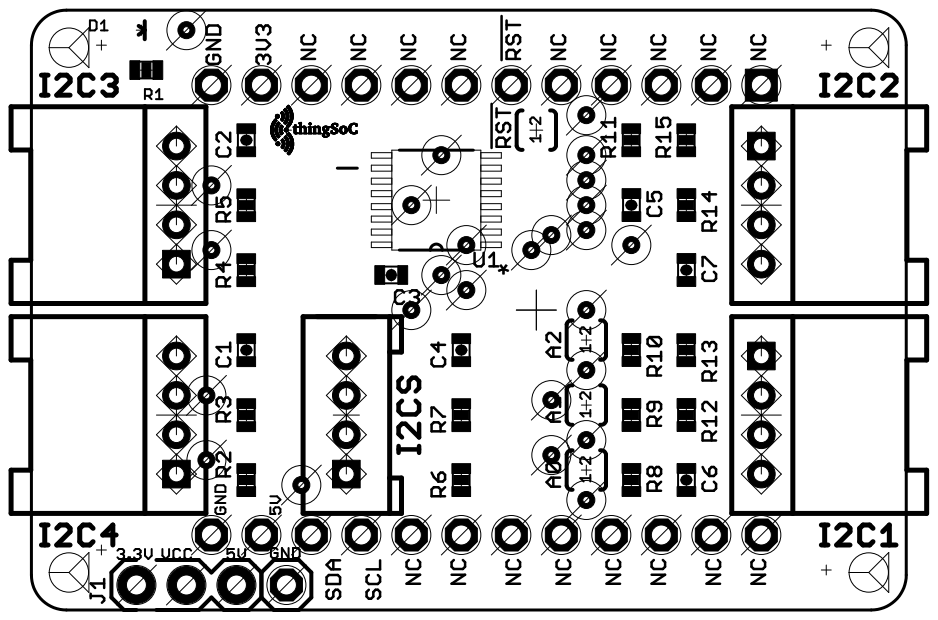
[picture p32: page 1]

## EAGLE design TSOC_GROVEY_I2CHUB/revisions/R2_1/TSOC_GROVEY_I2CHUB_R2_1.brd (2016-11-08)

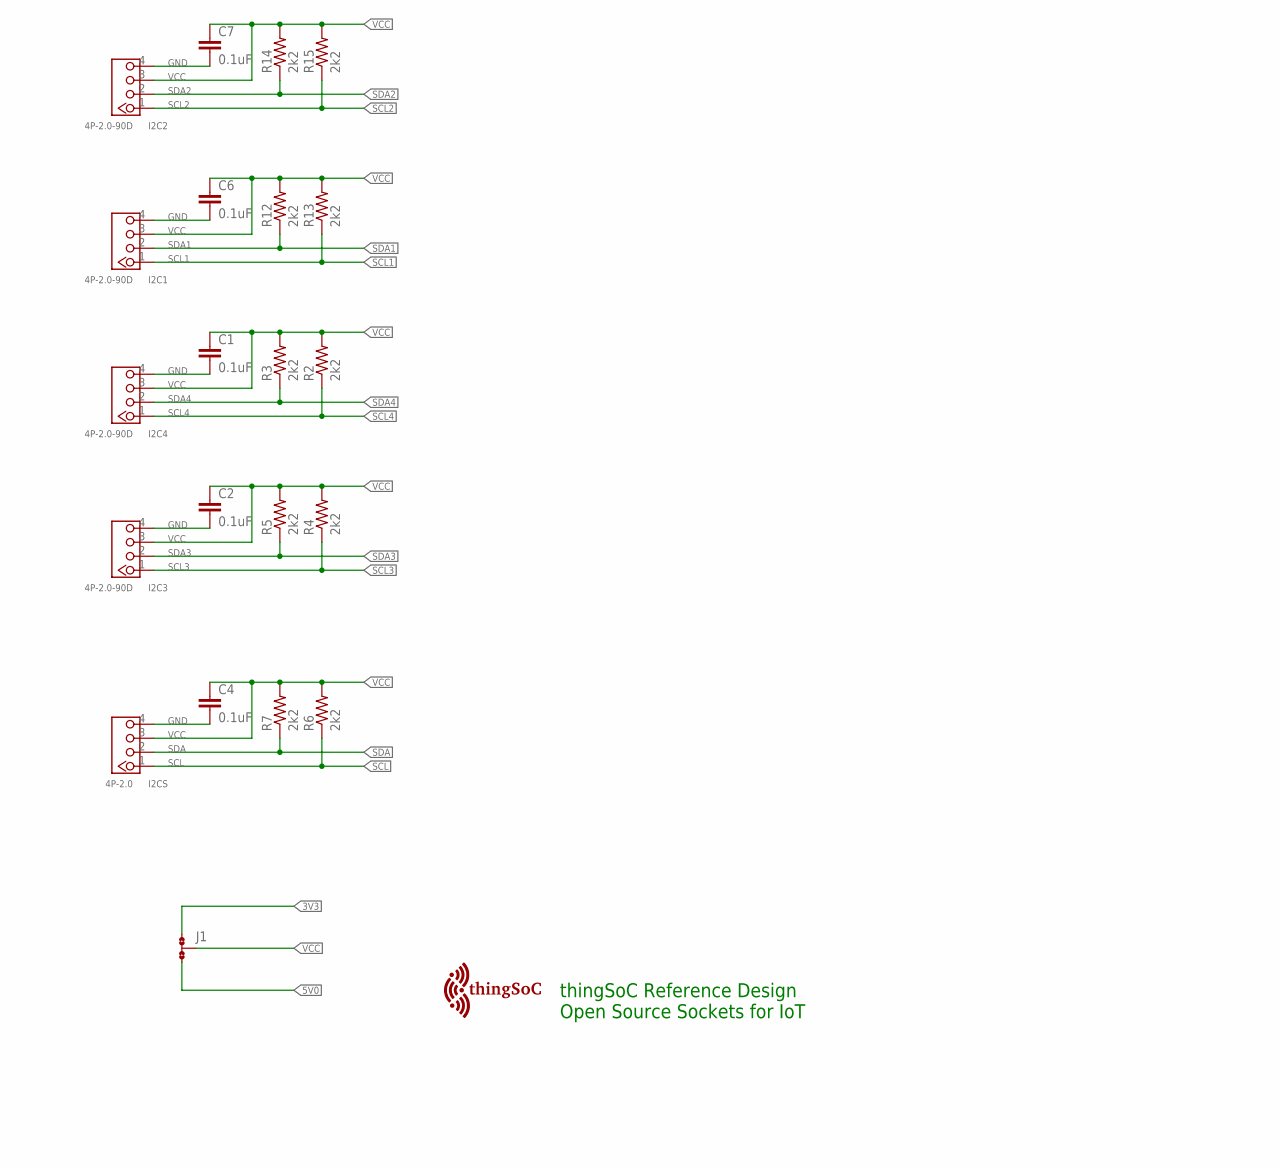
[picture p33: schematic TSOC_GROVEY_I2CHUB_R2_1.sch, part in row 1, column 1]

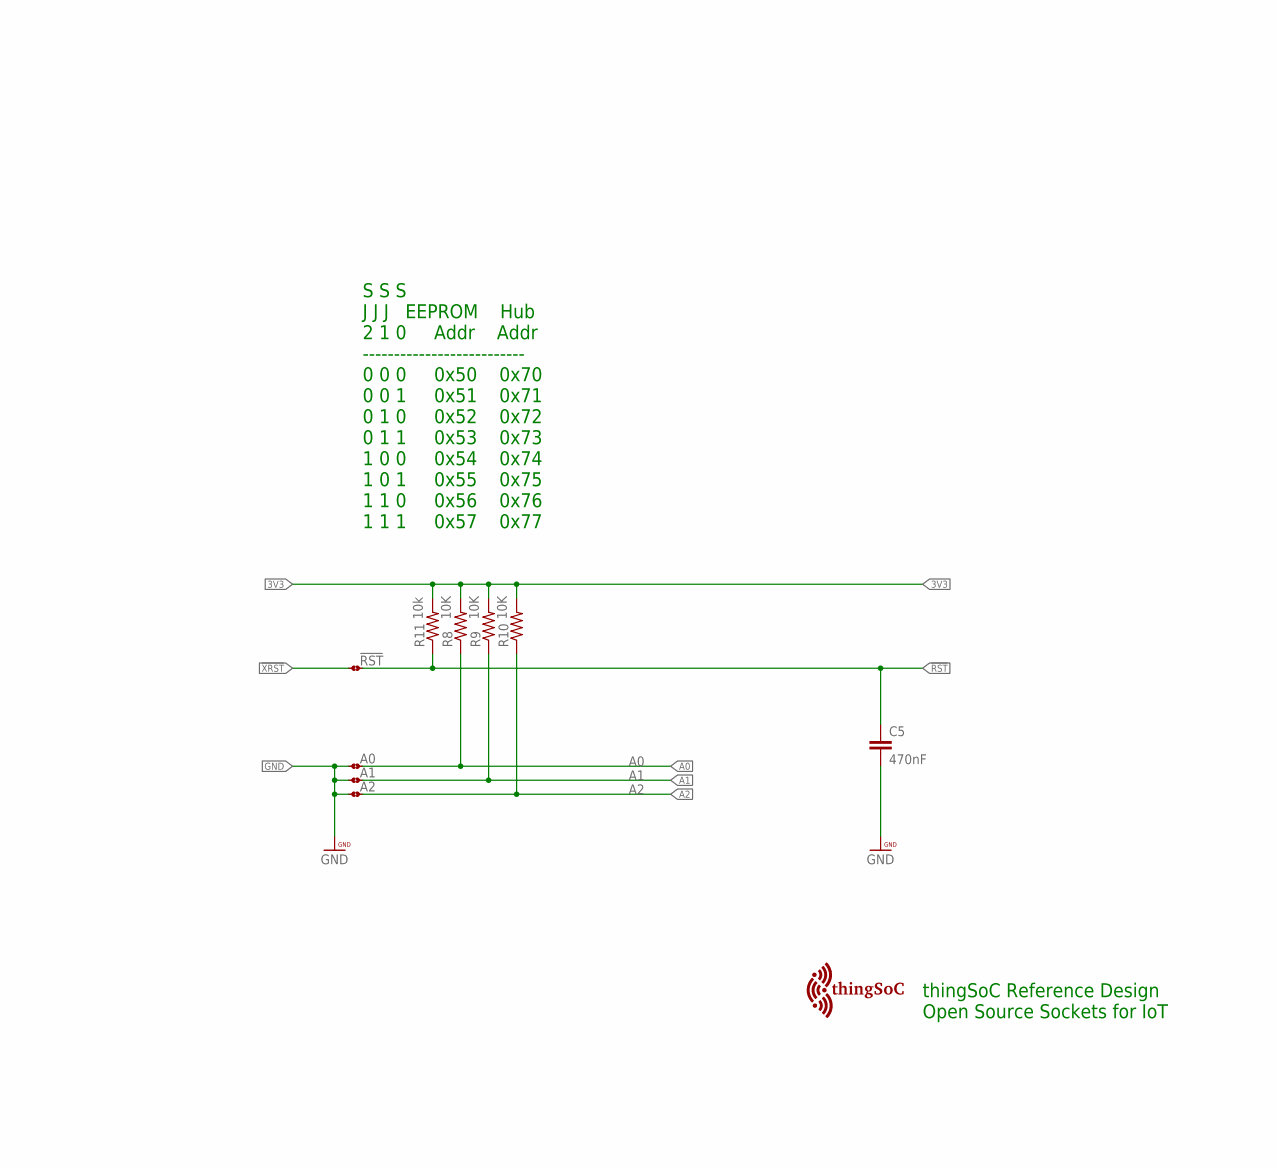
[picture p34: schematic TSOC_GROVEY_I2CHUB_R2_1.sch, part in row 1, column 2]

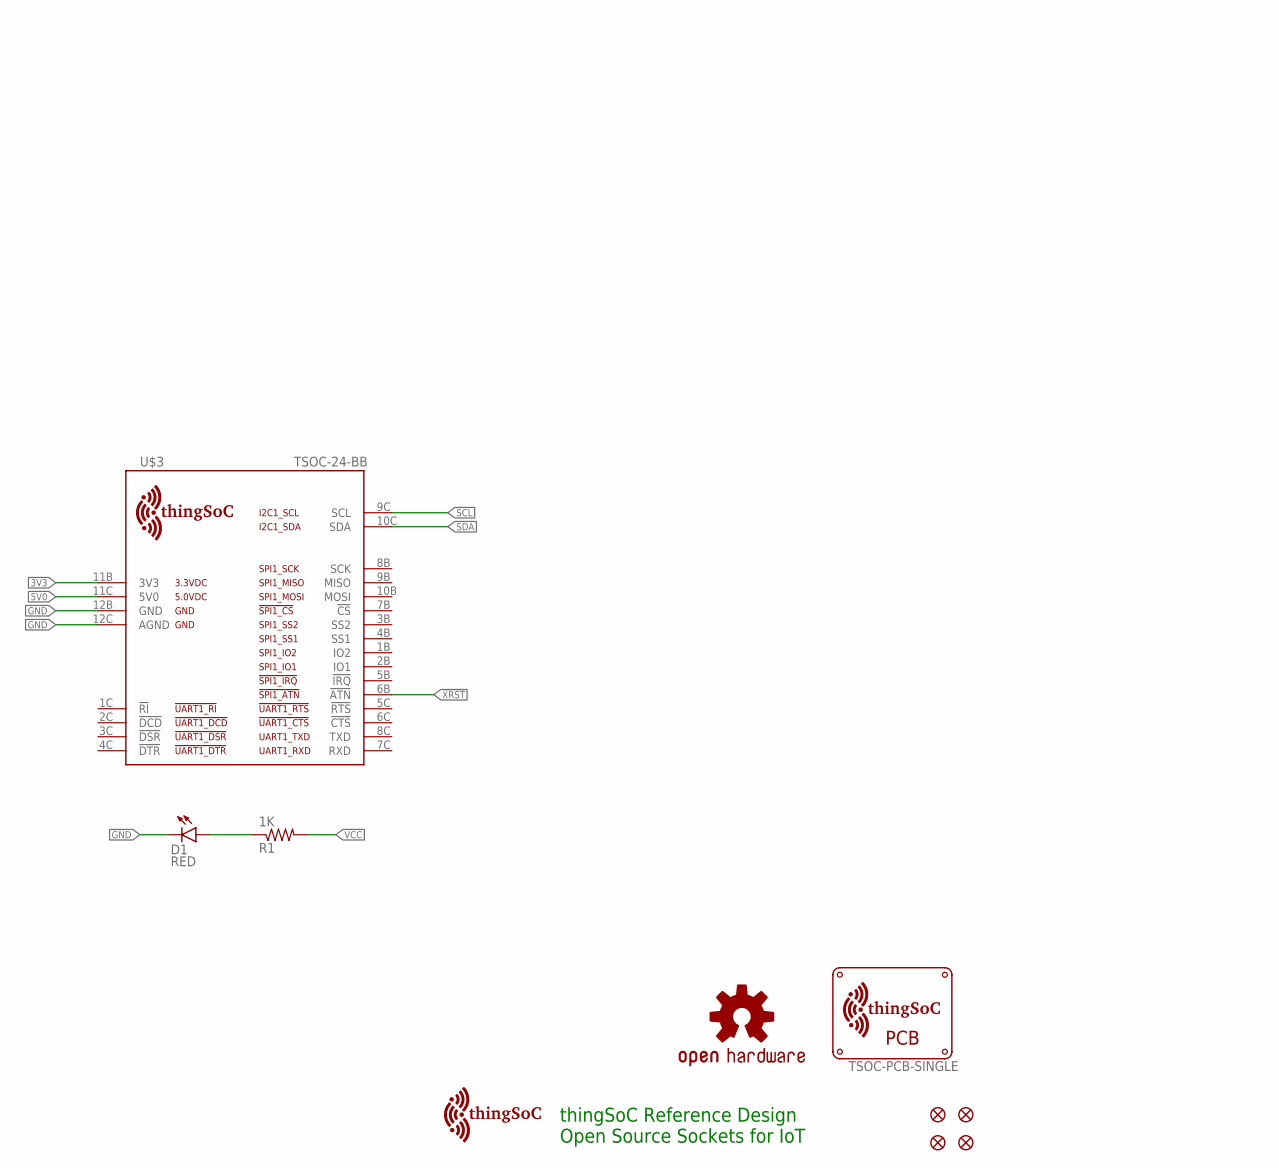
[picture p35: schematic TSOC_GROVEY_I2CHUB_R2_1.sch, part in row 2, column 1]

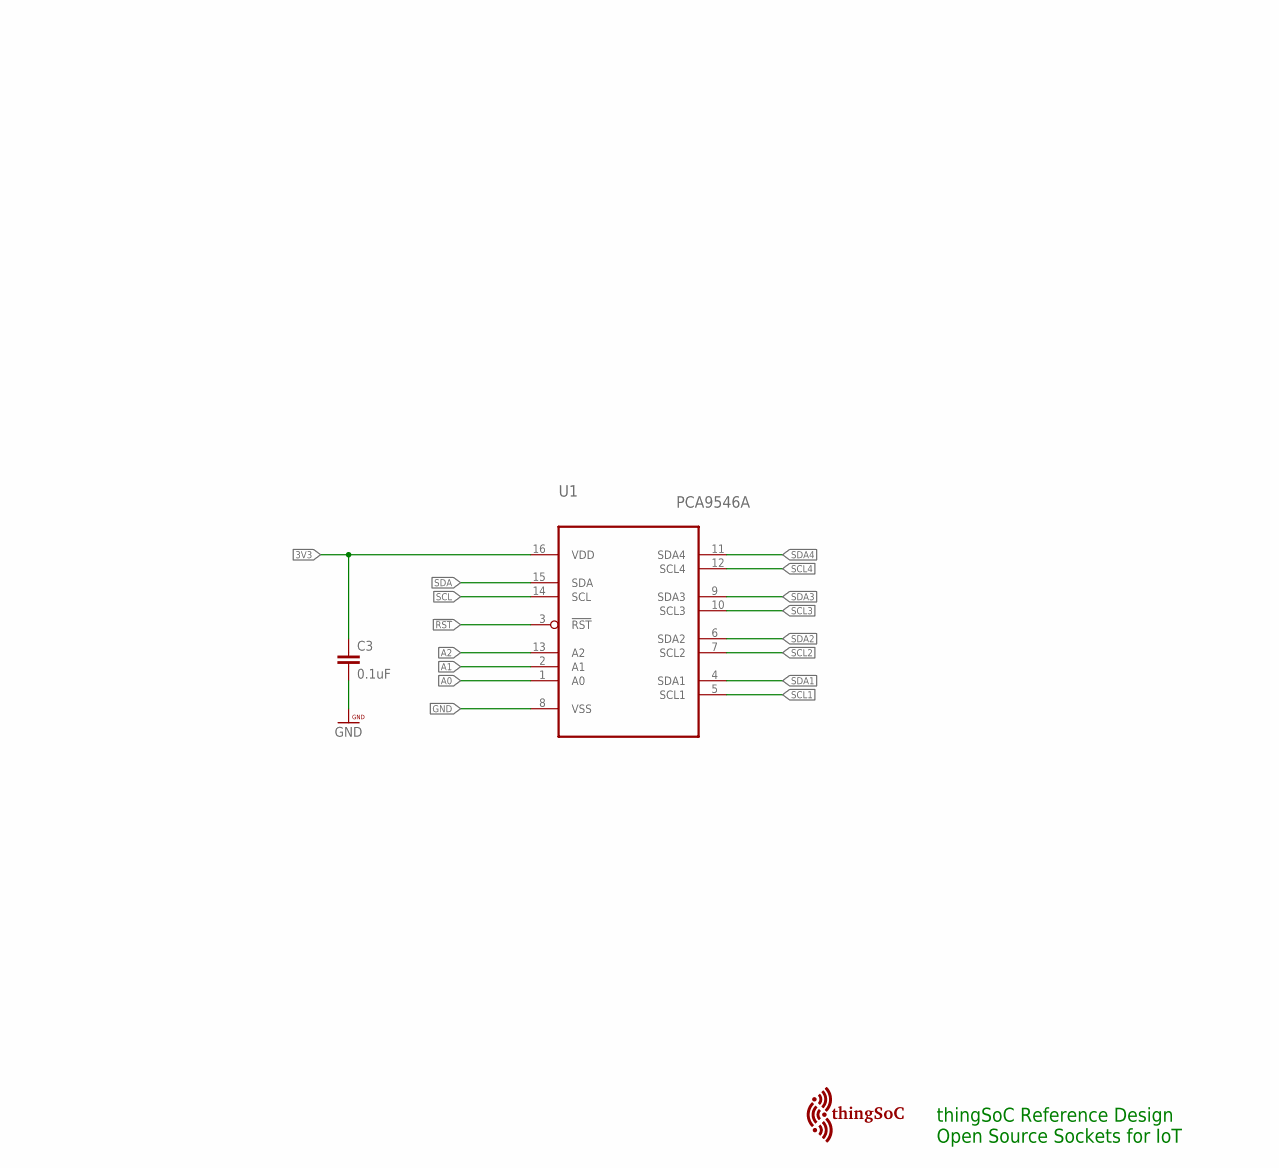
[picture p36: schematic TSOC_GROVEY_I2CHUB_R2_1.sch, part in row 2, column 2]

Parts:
!RST: NO; JMP-2-NO
A0, A1, A2: NO; JMP-2-NO
C1, C2, C3, C4, C6, C7: 0.1uF; 0603-CAP
C5: 470nF; 0603-CAP
D1: RED; LED-0603
FID1, FID2, FID3, FID4: FIDUCIALUFIDUCIAL; MICRO-FIDUCIAL
I2C1, I2C2, I2C3, I2C4: 4P-2.0-90D; HW4-2.0-90D
I2CS: 4P-2.0; HW4-2.0
J1: NO; JMP-3-NO-PTH-2.54
LOGO1: OSHW-LOGOL; OSHW-LOGO-L
R1: 1K; 0603-RES
R2, R3, R4, R5, R6, R7, R12, R13, R14, R15: 2k2; 0603-RES
R8, R9, R10: 10K; 0603-RES
R11: 10k; 0603-RES
U1: PCA9546A; SOP65P640X110-16N
U$1, U$102, U$103: TSOC-LOGO-SMALL; TSOC-LOGO-SML
U$2: TSOC-PCB-SINGLE; TSOC-BB-BRD-DIM
U$3: TSOC-24-BB; TSOC-BB-S24
U$101: TSOC-LOGO-LRG

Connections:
3V3: C3.1, J1.1, R8.2, R9.2, R10.2, R11.2, U1.16 (VDD), U$3.11B (3V3)
5V0: J1.3, U$3.11C (5V0)
!RST: !RST.1, C5.1, R11.1, U1.3 (!RST)
!XRST: !RST.2, U$3.6B (!ATN)
A0: A0.2, R8.1, U1.1 (A0)
A1: A1.2, R9.1, U1.2 (A1)
A2: A2.2, R10.1, U1.13 (A2)
GND: A0.1, A1.1, A2.1, C1.2, C2.2, C3.2, C4.2, C5.2, C6.2, C7.2, D1.C, I2C1.4, I2C2.4, I2C3.4, I2C4.4, I2CS.4, U1.8 (VSS), U$3.12B (GND), U$3.12C (AGND)
unnamed: D1.A, R1.1
SCL: I2CS.1, R6.1, U1.14 (SCL), U$3.9C (SCL)
SCL1: I2C1.1, R13.1, U1.5 (SCL1)
SCL2: I2C2.1, R15.1, U1.7 (SCL2)
SCL3: I2C3.1, R4.1, U1.10 (SCL3)
SCL4: I2C4.1, R2.1, U1.12 (SCL4)
SDA: I2CS.2, R7.1, U1.15 (SDA), U$3.10C (SDA)
SDA1: I2C1.2, R12.1, U1.4 (SDA1)
SDA2: I2C2.2, R14.1, U1.6 (SDA2)
SDA3: I2C3.2, R5.1, U1.9 (SDA3)
SDA4: I2C4.2, R3.1, U1.11 (SDA4)
VCC: C1.1, C2.1, C4.1, C6.1, C7.1, I2C1.3, I2C2.3, I2C3.3, I2C4.3, I2CS.3, J1.2, R1.2, R2.2, R3.2, R4.2, R5.2, R6.2, R7.2, R12.2, R13.2, R14.2, R15.2

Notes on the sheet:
S S S J J J EEPROM Hub 2 1 0 Addr Addr -------------------------- 0 0 0 0x50 0x70 0 0 1 0x51 0x71 0 1 0 0x52 0x72 0 1 1 0x53 0x73 1 0 0 0x54 0x74 1 0 1 0x55 0x75 1 1 0 0x56 0x76 1 1 1 0x57 0x77
thingSoC Reference Design Open Source Sockets for IoT

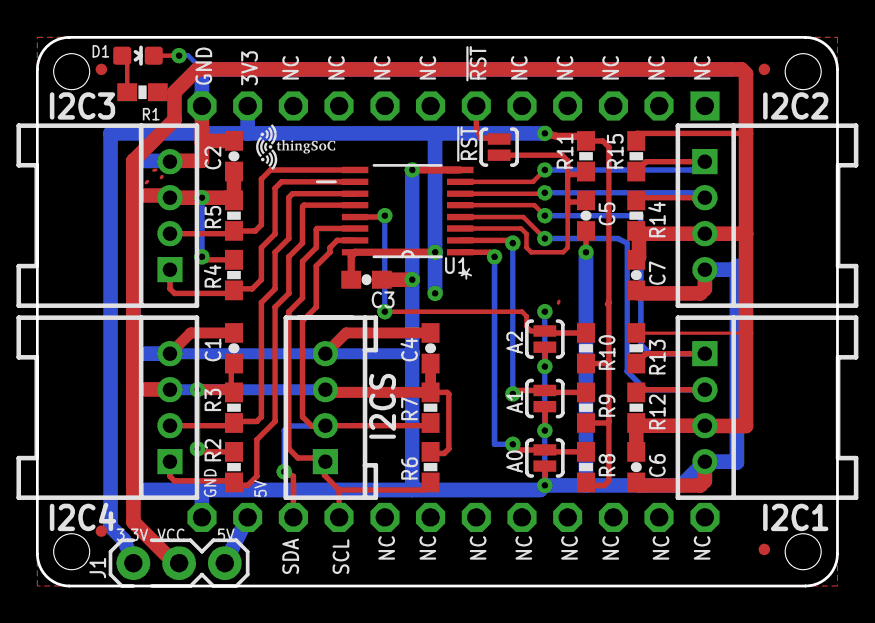
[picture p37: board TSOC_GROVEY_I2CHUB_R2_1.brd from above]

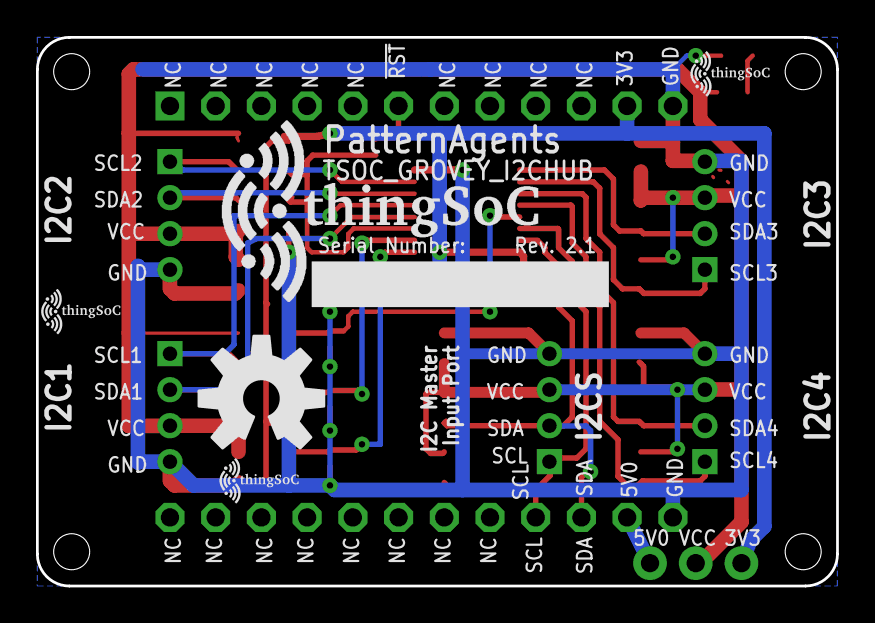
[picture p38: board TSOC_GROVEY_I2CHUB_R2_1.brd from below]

Board: 2 copper layers, 44.5 x 30.5 mm, 46 parts (5 on the bottom side), 20 nets.

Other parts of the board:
U$100: TSOC-LOGO-SMALL; TSOC-LOGO-SML

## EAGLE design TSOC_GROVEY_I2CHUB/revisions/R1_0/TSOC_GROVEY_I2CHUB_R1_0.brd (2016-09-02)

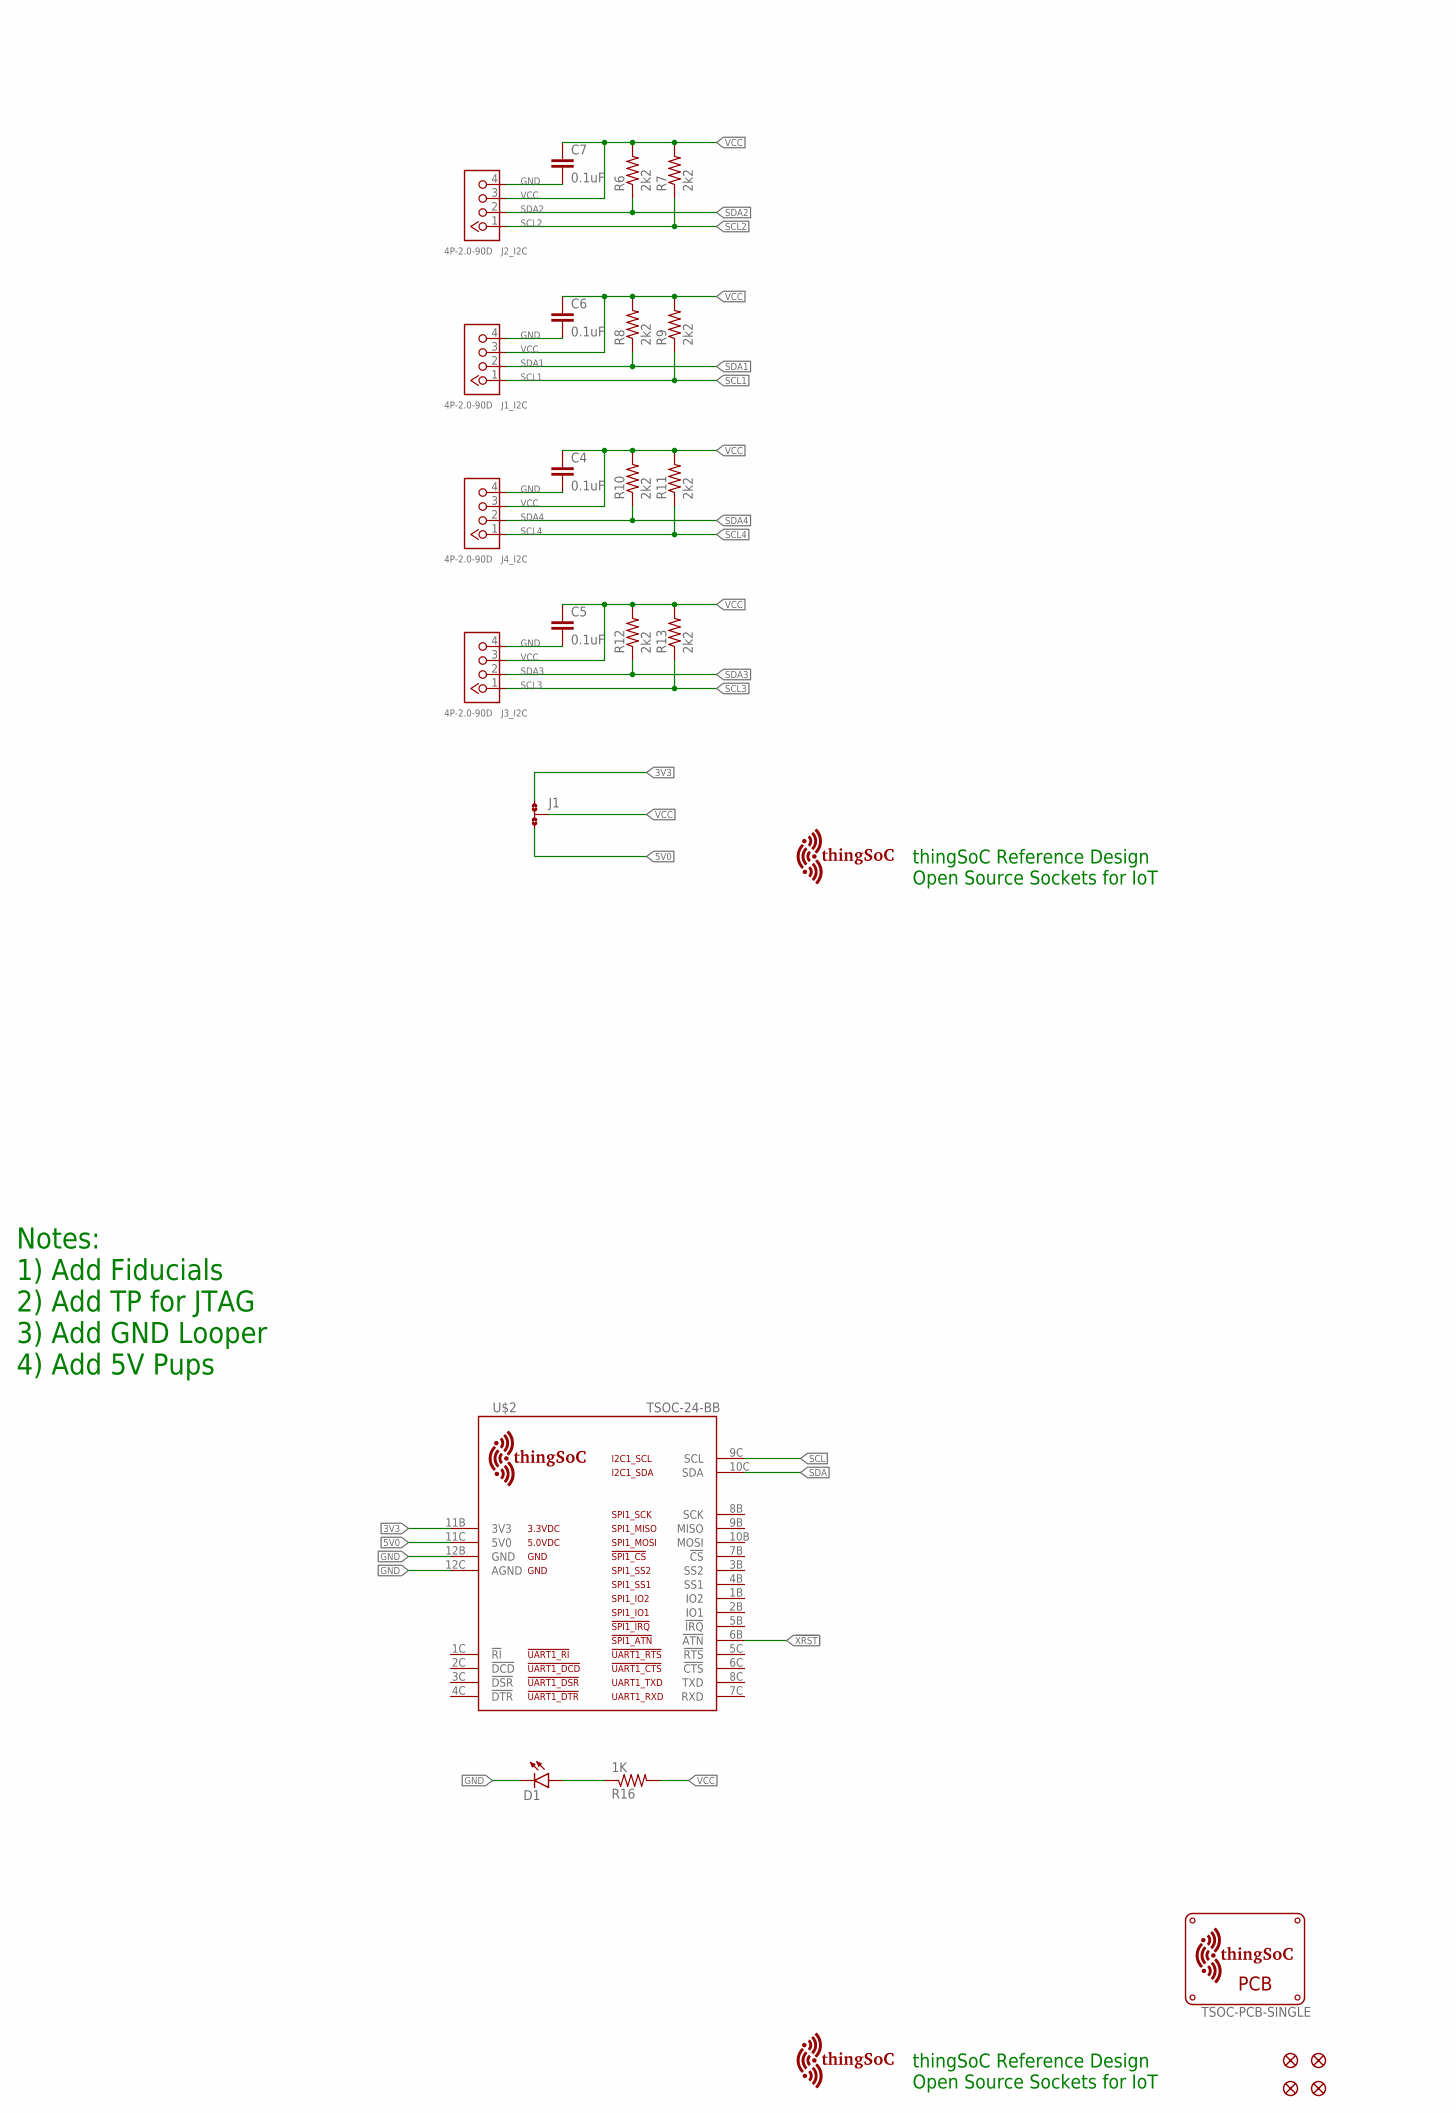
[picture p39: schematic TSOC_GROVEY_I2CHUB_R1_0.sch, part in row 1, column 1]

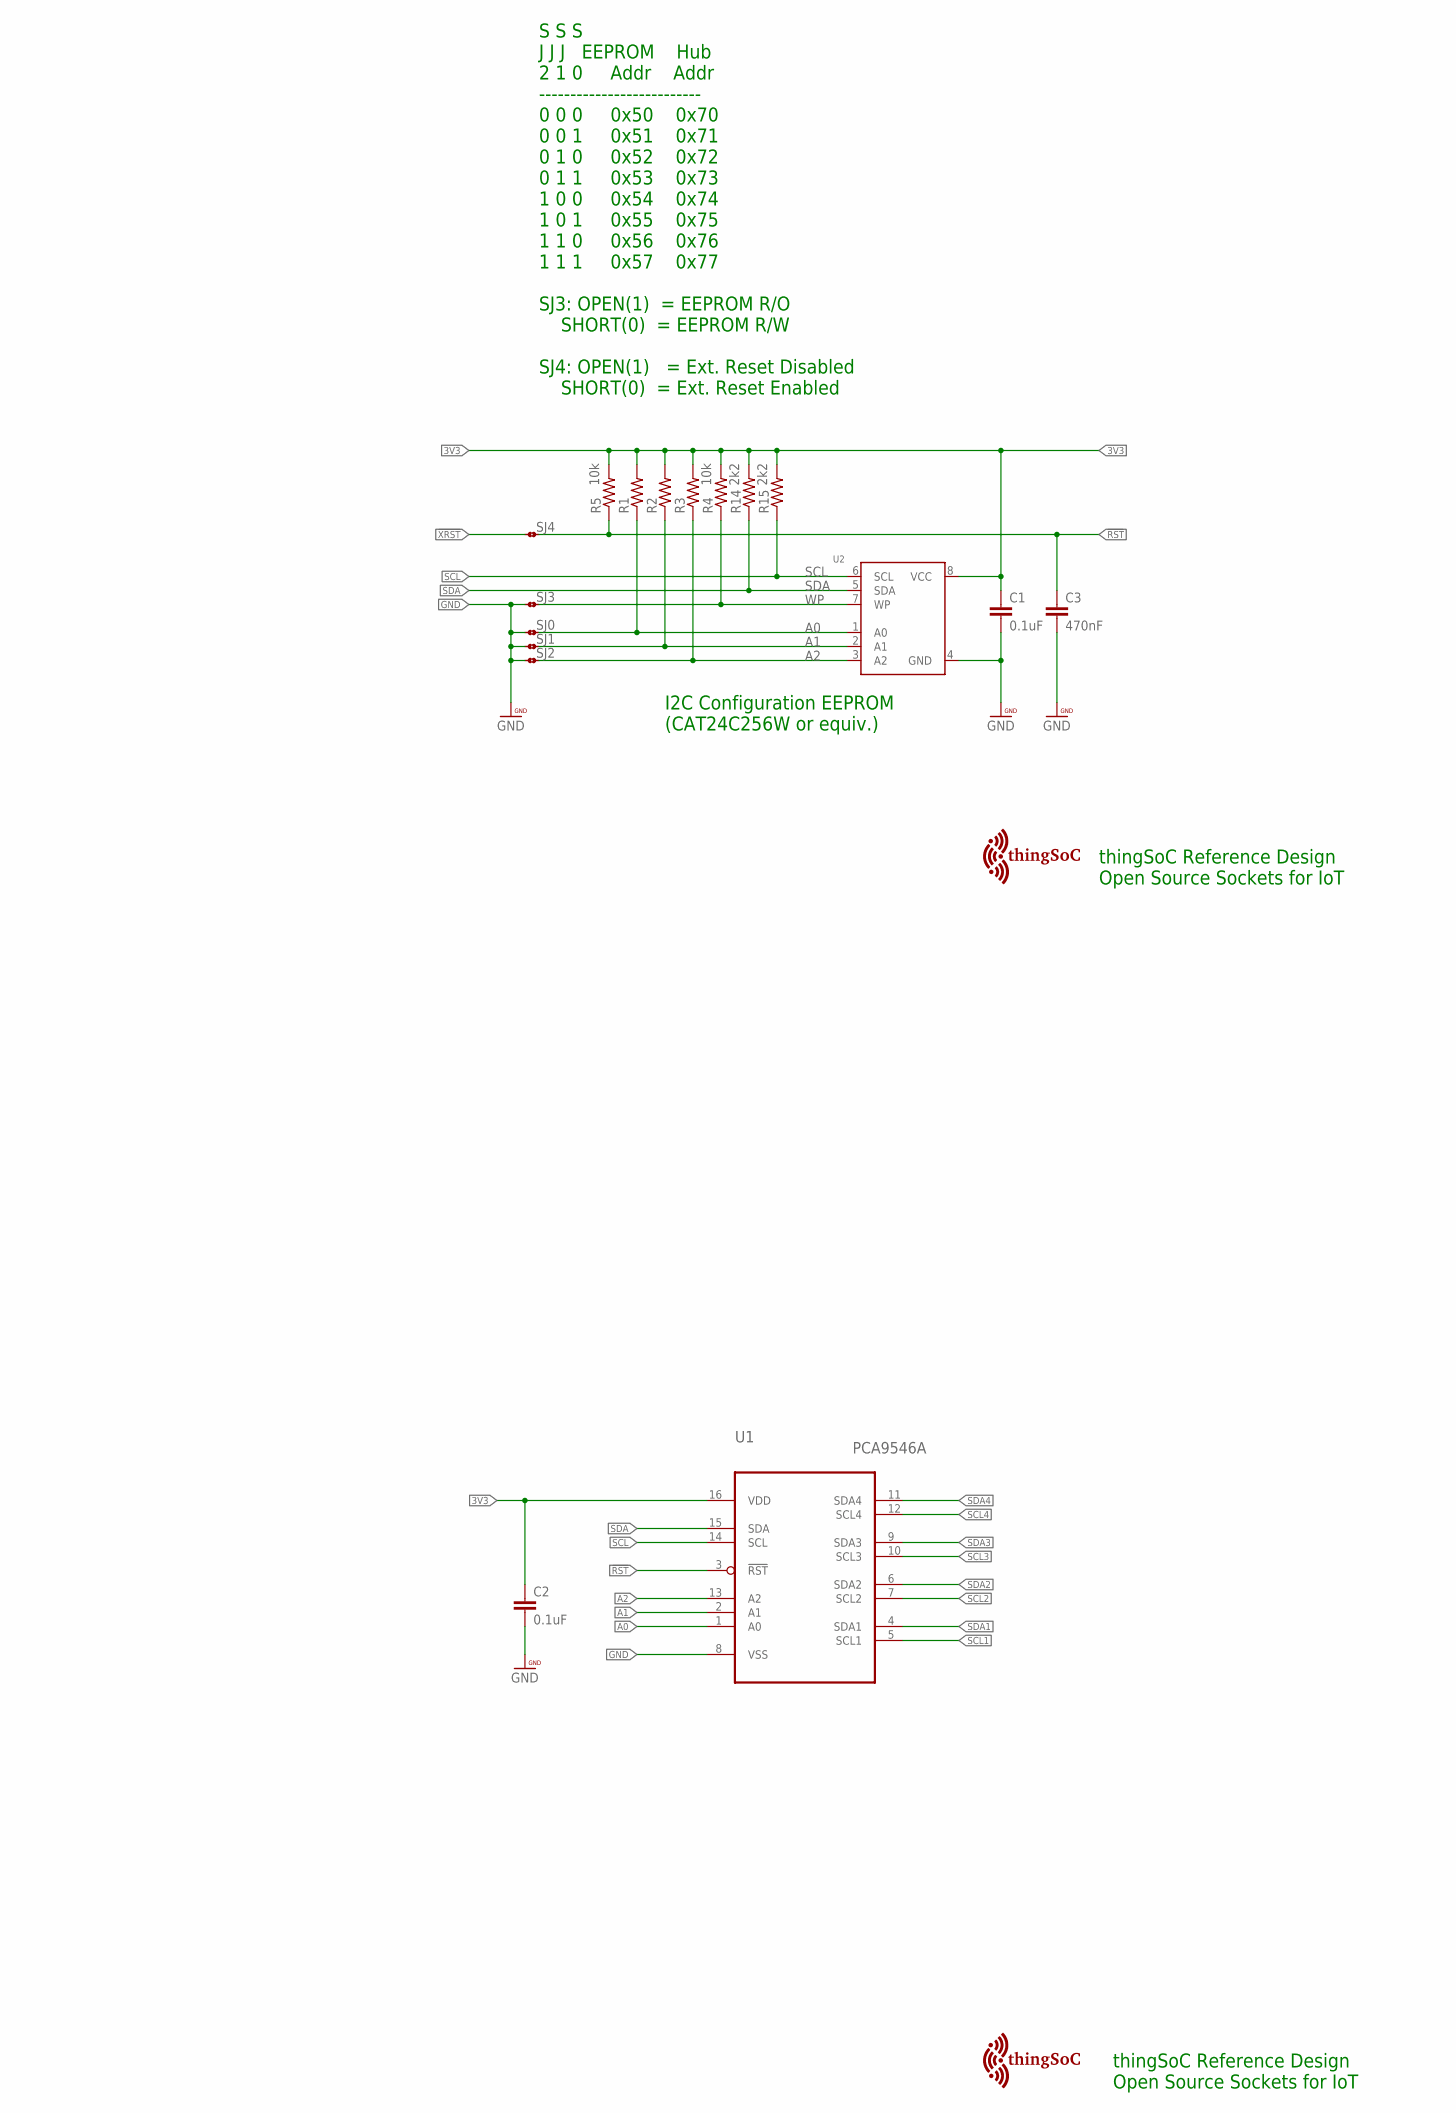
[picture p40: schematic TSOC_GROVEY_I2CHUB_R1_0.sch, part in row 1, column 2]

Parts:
C1, C2, C4, C5, C6, C7: 0.1uF; 0603-CAP
C3: 470nF; 0603-CAP
D1: LED0603; LED-0603
FID1, FID2, FID3, FID4: FIDUCIALUFIDUCIAL; MICRO-FIDUCIAL
J1: JMP-3-NO-PTH; JMP-3-NO-PTH-2.54
J1_I2C, J2_I2C, J3_I2C, J4_I2C: 4P-2.0-90D; HW4-2.0-90D
R1, R2, R3: RESISTOR0603-RES; 0603-RES
R4, R5: 10k; 0603-RES
R6, R7, R8, R9, R10, R11, R12, R13, R14, R15: 2k2; 0603-RES
R16: 1K; 0603-RES
SJ0, SJ1, SJ2, SJ3, SJ4: JMP-2-NO
U1: PCA9546A; SOP65P640X110-16N
U2: EEPROM_I2C_SOIC8_GENERIC; SOIC8_150MIL
U$1: TSOC-PCB-SINGLE; TSOC-BB-BRD-DIM
U$2: TSOC-24-BB; TSOC-BB-S24
U$7, U$9, U$100: TSOC-LOGO-SMALL; TSOC-LOGO-SML
U$101: TSOC-LOGO-LRG

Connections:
3V3: C1.1, C2.1, J1.1, R1.2, R2.2, R3.2, R4.2, R5.2, R14.2, R15.2, U1.16 (VDD), U2.8 (VCC), U$2.11B (3V3)
5V0: J1.3, U$2.11C (5V0)
!RST: C3.1, R5.1, SJ4.1, U1.3 (!RST)
!XRST: SJ4.2, U$2.6B (!ATN)
A0: R1.1, SJ0.2, U1.1 (A0), U2.1 (A0)
A1: R2.1, SJ1.2, U1.2 (A1), U2.2 (A1)
A2: R3.1, SJ2.2, U1.13 (A2), U2.3 (A2)
GND: C1.2, C2.2, C3.2, C4.2, C5.2, C6.2, C7.2, D1.C, J1_I2C.4, J2_I2C.4, J3_I2C.4, J4_I2C.4, SJ0.1, SJ1.1, SJ2.1, SJ3.1, U1.8 (VSS), U2.4 (GND), U$2.12B (GND), U$2.12C (AGND)
unnamed: D1.A, R16.1
SCL: R15.1, U1.14 (SCL), U2.6 (SCL), U$2.9C (SCL)
SCL1: J1_I2C.1, R9.1, U1.5 (SCL1)
SCL2: J2_I2C.1, R7.1, U1.7 (SCL2)
SCL3: J3_I2C.1, R13.1, U1.10 (SCL3)
SCL4: J4_I2C.1, R11.1, U1.12 (SCL4)
SDA: R14.1, U1.15 (SDA), U2.5 (SDA), U$2.10C (SDA)
SDA1: J1_I2C.2, R8.1, U1.4 (SDA1)
SDA2: J2_I2C.2, R6.1, U1.6 (SDA2)
SDA3: J3_I2C.2, R12.1, U1.9 (SDA3)
SDA4: J4_I2C.2, R10.1, U1.11 (SDA4)
VCC: C4.1, C5.1, C6.1, C7.1, J1.2, J1_I2C.3, J2_I2C.3, J3_I2C.3, J4_I2C.3, R6.2, R7.2, R8.2, R9.2, R10.2, R11.2, R12.2, R13.2, R16.2
WP: R4.1, SJ3.2, U2.7 (WP)

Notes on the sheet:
Notes: 1) Add Fiducials 2) Add TP for JTAG 3) Add GND Looper 4) Add 5V Pups
I2C Configuration EEPROM (CAT24C256W or equiv.)
S S S J J J EEPROM Hub 2 1 0 Addr Addr -------------------------- 0 0 0 0x50 0x70 0 0 1 0x51 0x71 0 1 0 0x52 0x72 0 1 1 0x53 0x73 1 0 0 0x54 0x74 1 0 1 0x55 0x75 1 1 0 0x56 0x76 1 1 1 0x57 0x77 SJ3: OPEN(1) = EEPROM R/O SHORT(0) = EEPROM R/W SJ4: OPEN(1) = Ext. Reset Disabled SHORT(0) = Ext. Reset 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
thingSoC Reference Design Open Source Sockets for IoT

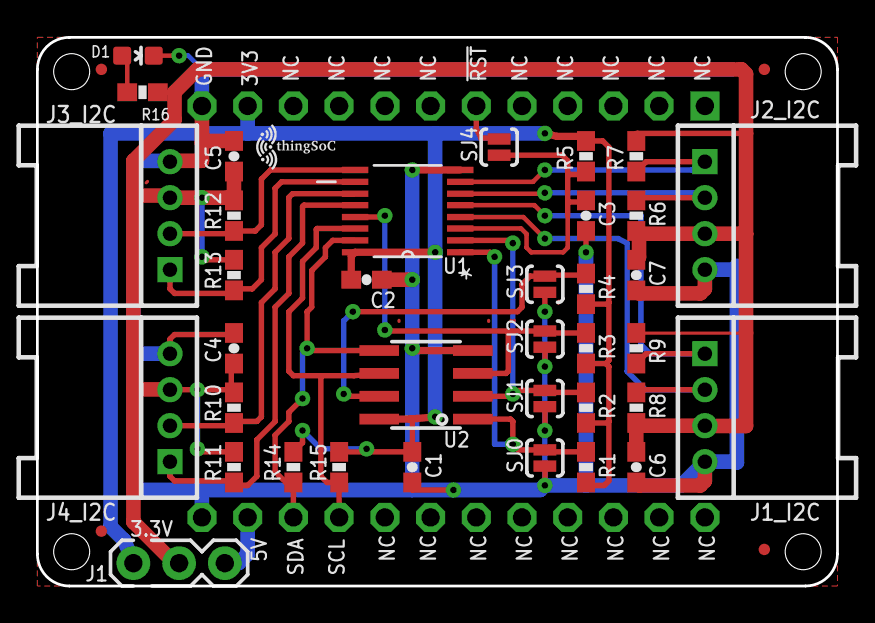
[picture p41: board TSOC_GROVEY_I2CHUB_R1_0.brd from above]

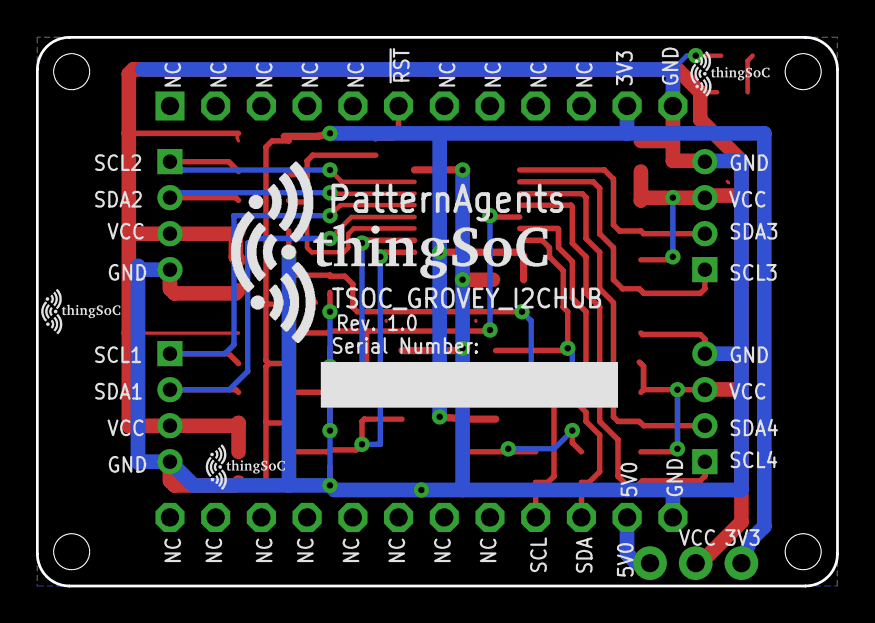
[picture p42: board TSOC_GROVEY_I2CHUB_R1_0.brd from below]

Board: 2 copper layers, 44.5 x 30.5 mm, 47 parts (4 on the bottom side), 21 nets.

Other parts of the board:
U$8: TSOC-LOGO-SMALL; TSOC-LOGO-SML

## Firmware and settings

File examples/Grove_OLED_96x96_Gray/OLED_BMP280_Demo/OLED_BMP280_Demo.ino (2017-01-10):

/*
  OLED FourScreenDemo Test for thingSoC I2C Hub (4 Port I2C Hub)
  2016 Copyright (c) PatternAgents, LLC.  All rights reserved.

  Author:Tom Moxon
  2016-12-18

  Requires :
  1) thingSoC/Arduino Compatible CPU
    (Teensy: https://github.com/thingSoC/TSOC_Teensy3x )
    (One: https://github.com/thingSoC/TSOC_GROVEY_ONE )
    (ESP8266: https://github.com/thingSoC/TSOC_GROVEY_WIFI ) 
  2) thingSoC Grovey I2C Hub Board (4 Port I2C Hub)
    (I2C HUB: https://github.com/thingSoC/TSOC_GROVEY_I2CHUB )
  3) Grove OLED Display 1.12" 96x96  (I2CHUB supports up to four of them)
    (LCD: http://wiki.seeed.cc/Grove-OLED_Display_1.12inch/ )

  Setup: (Important!)

  A) Plug Grove BMP280 Sensor into I2C3
  B) Plug Grove OLED into I2C4

------------------------------------------------------------------
  This library/program is free software; you can redistribute it and/or
  modify it under the terms of the GNU Lesser General Public
  License as published by the Free Software Foundation; either
  version 2.1 of the License, or (at your option) any later version.

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
  You should have received a copy of the GNU Lesser General Public
  License along with this library; if not, write to the Free Software
  Foundation, Inc., 51 Franklin St, Fifth Floor, Boston, MA  02110-1301  USA
------------------------------------------------------------------
*/
#include <Wire.h>
#include <SeeedGrayOLED.h>
#include <Seeed_BMP280.h>
#include <avr/pgmspace.h>
#include <PCA9546.h>
PCA9546 i2chub(0x73, PCA9546_CHANNEL_1);
BMP280 bmp280;
const int ledPin = 13;

static const unsigned char tsocLogo[] PROGMEM = {
0xFF, 0xFF, 0xFF, 0xFF, 0xFF, 0xFF, 0xFF, 0xFF, 0xFF, 0xFF, 0xFF, 0xFF, 0xFF, 0xFF, 0xFF, 0xFF,
0xFF, 0xFF, 0xFF, 0xFF, 0xFF, 0xFF, 0xFF, 0xFF, 0xFF, 0xFF, 0xFF, 0xFF, 0xFF, 0xFF, 0xFF, 0xFF,
0xFF, 0xFF, 0xFF, 0xFF, 0xFF, 0xFF, 0xFF, 0xFF, 0xFF, 0xFF, 0xFF, 0xFF, 0xFF, 0xFF, 0xFF, 0xFF,
0xFF, 0xFF, 0xFF, 0xFF, 0xFF, 0xFF, 0xFF, 0xFF, 0xFF, 0xFF, 0xFF, 0xFF, 0xFF, 0xFF, 0xFF, 0xFF,
0xFF, 0xFF, 0xFF, 0xFF, 0xFF, 0xFF, 0xFF, 0xFF, 0xFF, 0xFF, 0xFF, 0xFF, 0xFF, 0xFF, 0xFF, 0xFF,
0xFF, 0xFF, 0xFF, 0xFF, 0xFF, 0xFF, 0xFF, 0xFF, 0xFF, 0xFF, 0xFF, 0xFF, 0xFF, 0xFF, 0xFF, 0xFF,
0xFF, 0xFF, 0xFF, 0xFF, 0xFF, 0xFF, 0xFF, 0xFF, 0xFF, 0xFF, 0xFF, 0xFF, 0xFF, 0xFF, 0xFF, 0xFF,
0xFF, 0xFF, 0xFF, 0xFF, 0xFF, 0xFF, 0xFF, 0xFF, 0xFF, 0xFF, 0xFF, 0xFF, 0xFF, 0xFF, 0xFF, 0xFF,
0xFF, 0xFF, 0xFF, 0xFF, 0xFF, 0xFF, 0xFF, 0xFF, 0xFF, 0xFF, 0xFF, 0xFF, 0xFF, 0xFF, 0xFF, 0xFF,
0xFF, 0xFF, 0xFF, 0xFF, 0xFF, 0xFF, 0xFF, 0xFF, 0xFF, 0xFF, 0xFF, 0xFF, 0xFF, 0xFF, 0xFF, 0xFF,
0xFF, 0xFF, 0xFF, 0xFF, 0xFF, 0xFF, 0xFF, 0xFF, 0xFF, 0xFF, 0xFF, 0xFF, 0xFF, 0xFF, 0xFF, 0xFF,
0xFF, 0xFF, 0xFF, 0xFF, 0xFF, 0xFF, 0xFF, 0xFF, 0xFF, 0xFF, 0xFF, 0xFF, 0xFF, 0xFF, 0xFF, 0xFF,
0xFF, 0xFF, 0xFF, 0xFF, 0xFF, 0xFF, 0xFF, 0xFF, 0xFF, 0xFF, 0xFF, 0xFF, 0xFF, 0xFF, 0xFF, 0xFF,
0xFF, 0xFF, 0xFF, 0xFF, 0xFF, 0xFF, 0xFF, 0xFF, 0xFF, 0xFF, 0xFF, 0xFF, 0xFF, 0xFF, 0xFF, 0xFF,
0xFF, 0xFF, 0xFF, 0xFF, 0xFF, 0xFF, 0xFF, 0xFF, 0xFF, 0xFF, 0xFF, 0xFF, 0xFF, 0xFF, 0xFF, 0xFF,
0xFF, 0xFF, 0xFF, 0xFF, 0xFF, 0xFF, 0xFF, 0xFF, 0xFF, 0xFF, 0xFF, 0xFF, 0xFF, 0xFF, 0xE7, 0xFF,
0xFF, 0xFF, 0xFF, 0xFF, 0xFF, 0xFF, 0xFF, 0xFF, 0xFF, 0xFF, 0xC3, 0xFF, 0xFF, 0xFF, 0xFF, 0xFF,
0xFF, 0xFF, 0xFF, 0xFF, 0xFF, 0xFF, 0x81, 0xFF, 0xFF, 0xFF, 0xFF, 0xFF, 0xFF, 0xFF, 0xFF, 0xFF,
0xFF, 0xFF, 0x01, 0xFF, 0xFF, 0xFF, 0xFF, 0xFF, 0xFF, 0xFF, 0xFF, 0xFF, 0xFF, 0xFE, 0x20, 0xFF,
0xFF, 0xFF, 0xFF, 0xFF, 0xFF, 0xFF, 0xFF, 0xFF, 0xFF, 0xFC, 0x00, 0xFF, 0xFF, 0xFF, 0xFF, 0xFF,
0xFF, 0xFF, 0xFF, 0xFF, 0xFF, 0xFA, 0x00, 0x7F, 0xFF, 0xFF, 0xFF, 0xFF, 0xFF, 0xFF, 0xFF, 0xFF,
0xFF, 0xF1, 0x08, 0x7F, 0xFF, 0xFF, 0xFF, 0xFF, 0xFF, 0xFF, 0xFF, 0xFF, 0xFF, 0xE1, 0x00, 0x7F,
0xFF, 0xFF, 0xFF, 0xFF, 0xFF, 0xFF, 0xFF, 0xFF, 0xFF, 0xE0, 0x00, 0x7F, 0xFF, 0xFF, 0xFF, 0xFF,
0xFF, 0xFF, 0xFF, 0xFF, 0xFC, 0x30, 0x80, 0x7F, 0xFF, 0xFF, 0xFF, 0xFF, 0xFF, 0xFF, 0xFF, 0xFF,
0xFC, 0x10, 0x84, 0x3F, 0xFF, 0xFF, 0xFF, 0xFF, 0xFF, 0xFF, 0xFF, 0xFF, 0xF8, 0x10, 0x84, 0x3F,
0xFF, 0xFF, 0xFF, 0xFF, 0xFF, 0xFF, 0xFF, 0xFF, 0xFC, 0x10, 0x84, 0x3F, 0xFF, 0xFF, 0xFF, 0xFF,
0xFF, 0xFF, 0xFF, 0xFF, 0xF8, 0x20, 0x80, 0x7F, 0xFF, 0xFF, 0xFF, 0xFF, 0xFF, 0xFF, 0xFF, 0xFF,
0xF8, 0xE0, 0x00, 0x7F, 0xFF, 0xFF, 0xFF, 0xFF, 0xFF, 0xFF, 0xFF, 0xFF, 0xE0, 0xE1, 0x00, 0x7F,
0xFF, 0xFF, 0xFF, 0xFF, 0xFF, 0xFF, 0xFF, 0xFF, 0xE0, 0xF0, 0x00, 0x7F, 0xFF, 0xFF, 0xFF, 0xFF,
0xFF, 0xFF, 0xFF, 0xFF, 0xC1, 0x1C, 0x10, 0x7F, 0x1F, 0xFF, 0xFF, 0xFF, 0xFF, 0xFF, 0xFF, 0xFF,
0xC0, 0x0C, 0x00, 0xFC, 0x1F, 0x87, 0xFF, 0xFF, 0xE0, 0x7F, 0xFE, 0x07, 0x82, 0x0E, 0x20, 0xEC,
0x1F, 0x87, 0xFF, 0xFF, 0xC0, 0x7F, 0xFC, 0x03, 0x80, 0x03, 0xC1, 0xC6, 0x1F, 0xC7, 0xFF, 0xFF,
0x86, 0x7F, 0xF8, 0x63, 0x84, 0x21, 0x83, 0x80, 0x01, 0x84, 0x03, 0x80, 0x86, 0x70, 0x70, 0xE3,
0x80, 0x01, 0xC3, 0x00, 0x01, 0x00, 0x03, 0x00, 0x06, 0x60, 0x30, 0xF3, 0x00, 0x41, 0x07, 0x00,
0x00, 0x00, 0x01, 0x10, 0x01, 0xC2, 0x01, 0xFF, 0x00, 0x42, 0x0F, 0x86, 0x10, 0x84, 0x21, 0x10,
0xC0, 0x43, 0x01, 0xFF, 0x00, 0x02, 0x07, 0x86, 0x10, 0x84, 0x21, 0x10, 0xE0, 0x43, 0x01, 0xFF,
0x00, 0x42, 0x07, 0x86, 0x10, 0x84, 0x21, 0x01, 0x98, 0x43, 0x10, 0xE3, 0x00, 0x42, 0x0F, 0x86,
0x10, 0x84, 0x21, 0x87, 0x8C, 0x43, 0x10, 0xE3, 0x00, 0x41, 0x83, 0x80, 0x10, 0x04, 0x21, 0x80,
0x80, 0x40, 0x18, 0x03, 0x84, 0x01, 0xC3, 0x80, 0x00, 0x00, 0x00, 0x00, 0x80, 0xE0, 0x3C, 0x03,
0x84, 0x23, 0xC1, 0xC0, 0x00, 0x00, 0x01, 0x00, 0x81, 0xF0, 0x7E, 0x07, 0x80, 0x13, 0xC0, 0xFF,
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
};

void setDisplayToOriginalState()
{
    SeeedGrayOled.init();
}

int i;
void setup()
{
      pinMode(ledPin, OUTPUT);    /* initialize the digital pin as an output */
      digitalWrite(ledPin, HIGH); /* set the LED on */
      Wire.begin(); /* Start the I2C Bus */
      
      i2chub.selectChannel(PCA9546_CHANNEL_4); /* select I2C Channel 4 - the OLED Display */
      /* set up the LCD's number of columns and rows */
      setDisplayToOriginalState();  
      SeeedGrayOled.clearDisplay();                  //  clear the screen and set start position to top left corner
      SeeedGrayOled.setInverseDisplay();             // Set Display to inverse mode
      SeeedGrayOled.drawBitmap(tsocLogo,96*96/8);   //  Draw binary Bitmap (96 pixels *96 pixels  / 8) bytes
      delay(500);
      digitalWrite(ledPin, LOW);
      delay(500);
      i2chub.selectChannel(PCA9546_CHANNEL_3); /* select I2C Channel 3 - the BMP280 Sensor */
      digitalWrite(ledPin, HIGH);
      delay(500);
      if(bmp280.init()== false) {
          i2chub.selectChannel(PCA9546_CHANNEL_4);
          setDisplayToOriginalState();  
          SeeedGrayOled.clearDisplay();     //Clear Display.
          SeeedGrayOled.setNormalDisplay(); //Set Normal Display Mode
          SeeedGrayOled.setVerticalMode();  // Set to vertical mode for displaying text
          SeeedGrayOled.setGrayLevel(15); //Set Grayscale level. Any number between 0 - 15.
          SeeedGrayOled.setTextXY(0,0);  //set Cursor to 0th line, 0th column
          SeeedGrayOled.putString("BMP280 FAIL");
          SeeedGrayOled.setTextXY(1,0);
          SeeedGrayOled.putString("Barometer");
          SeeedGrayOled.setTextXY(2,0);
          SeeedGrayOled.putString("Sensor");
          SeeedGrayOled.setTextXY(3,0);
          SeeedGrayOled.putString("Unplugged!");
          SeeedGrayOled.setTextXY(5,0);
          SeeedGrayOled.putString("Plug Sensor");
          SeeedGrayOled.setTextXY(6,0);
          SeeedGrayOled.putString("Into I2C3 !");
          while (1) {};
      } else {
          i2chub.selectChannel(PCA9546_CHANNEL_4);
          setDisplayToOriginalState();  
          SeeedGrayOled.clearDisplay();     //Clear Display.
          SeeedGrayOled.setNormalDisplay(); //Set Normal Display Mode
          SeeedGrayOled.setVerticalMode();  // Set to vertical mode for displaying text
          SeeedGrayOled.setGrayLevel(15); //Set Grayscale level. Any number between 0 - 15.
          SeeedGrayOled.setTextXY(0,0);  //set Cursor to 0th line, 0th column
          SeeedGrayOled.putString("BMP280 OKAY");
          SeeedGrayOled.setTextXY(1,0);
          SeeedGrayOled.putString("Barometer");
          SeeedGrayOled.setTextXY(2,0);
          SeeedGrayOled.putString("Sensor");
          SeeedGrayOled.setTextXY(3,0);
          SeeedGrayOled.putString("Found!");
          SeeedGrayOled.setTextXY(5,0);
          SeeedGrayOled.putString("Sensor");
          SeeedGrayOled.setTextXY(6,0);
          SeeedGrayOled.putString("On I2C3 !");
          delay(2000);
      }
      
      digitalWrite(ledPin, LOW);
      /* reset the OLED Display */
      i2chub.selectChannel(PCA9546_CHANNEL_4);
      setDisplayToOriginalState();     
      SeeedGrayOled.clearDisplay();
      SeeedGrayOled.setVerticalMode();  // Set to vertical mode for displaying text
      SeeedGrayOled.setGrayLevel(15); //Set Grayscale level. Any number between 0 - 15.

}
float cur_Temperature;
uint32_t cur_Pressure;

void loop()
{
     digitalWrite(ledPin, HIGH); /* set the LED on */
     i2chub.selectChannel(PCA9546_CHANNEL_3);
     cur_Temperature = bmp280.getTemperature();
     cur_Pressure = bmp280.getPressure()/100;
     i2chub.selectChannel(PCA9546_CHANNEL_4);
          SeeedGrayOled.setTextXY(0,0);  //set Cursor to 0th line, 0th column
          SeeedGrayOled.putString("BMP280     ");
          SeeedGrayOled.setTextXY(2,0);
          SeeedGrayOled.putString("Barometer");
          SeeedGrayOled.setTextXY(3,0);
          SeeedGrayOled.putString("            ");
          SeeedGrayOled.setTextXY(3,0);
          SeeedGrayOled.putNumber(cur_Pressure);
          SeeedGrayOled.setTextXY(4,0);
          SeeedGrayOled.putString("hPa");
          SeeedGrayOled.setTextXY(6,0);
          SeeedGrayOled.putString("Temperature");
          SeeedGrayOled.setTextXY(7,0);
          SeeedGrayOled.putString("            ");
          SeeedGrayOled.setTextXY(7,0);
          SeeedGrayOled.putNumber(cur_Temperature);
          SeeedGrayOled.setTextXY(8,0);
          SeeedGrayOled.putString("Deg. Celsius");
      delay(500);
      digitalWrite(ledPin, LOW);
      delay(500);
}

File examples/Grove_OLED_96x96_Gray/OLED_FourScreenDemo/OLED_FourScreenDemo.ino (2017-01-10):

/*
  OLED FourScreenDemo Test for thingSoC I2C Hub (4 Port I2C Hub)
  2016 Copyright (c) PatternAgents, LLC.  All rights reserved.

  Author:Tom Moxon
  2016-12-18

  Requires :
  1) thingSoC/Arduino Compatible CPU
    (Teensy: https://github.com/thingSoC/TSOC_Teensy3x )
    (One: https://github.com/thingSoC/TSOC_GROVEY_ONE )
    (ESP8266: https://github.com/thingSoC/TSOC_GROVEY_WIFI ) 
  2) thingSoC Grovey I2C Hub Board (4 Port I2C Hub)
    (I2C HUB: https://github.com/thingSoC/TSOC_GROVEY_I2CHUB )
  3) Grove OLED Display 1.12" 96x96  (I2CHUB supports up to four of them)
    (LCD: http://wiki.seeed.cc/Grove-OLED_Display_1.12inch/ )

------------------------------------------------------------------
  This library/program is free software; you can redistribute it and/or
  modify it under the terms of the GNU Lesser General Public
  License as published by the Free Software Foundation; either
  version 2.1 of the License, or (at your option) any later version.

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
  You should have received a copy of the GNU Lesser General Public
  License along with this library; if not, write to the Free Software
  Foundation, Inc., 51 Franklin St, Fifth Floor, Boston, MA  02110-1301  USA
------------------------------------------------------------------
*/
#include <Wire.h>
#include <SeeedGrayOLED.h>
#include <avr/pgmspace.h>
#include <PCA9546.h>
PCA9546 i2chub(PCA9546_ADDR_7, PCA9546_CHANNEL_1);
const int ledPin = 13;

const unsigned char oshwLogo [] = {
0xFF, 0xFF, 0xFF, 0xFF, 0xFF, 0xFF, 0xFF, 0xFF, 0xFF, 0xFF, 0xFF, 0xFF, 0xFF, 0xFF, 0xFF, 0xFF,
0xFF, 0xFF, 0xFF, 0xFF, 0xFF, 0xFF, 0xFF, 0xFF, 0xFF, 0xFF, 0xFF, 0xFF, 0xFF, 0xFF, 0xFF, 0xFF,
0xFF, 0xFF, 0xFF, 0xFF, 0xFF, 0xFF, 0xFF, 0xFF, 0xFF, 0xFF, 0xFF, 0xFF, 0xFF, 0xFF, 0xFF, 0xFF,
0xFF, 0xFF, 0xFF, 0xFF, 0xFF, 0xFF, 0xFF, 0xFF, 0xFF, 0xFF, 0xFF, 0xFF, 0xFF, 0xFF, 0xFF, 0xFF,
0xFF, 0xFF, 0xFF, 0xFF, 0xFF, 0xFF, 0xFF, 0xFF, 0xFF, 0xFF, 0xFF, 0xFF, 0xFF, 0xFF, 0xFF, 0xFF,
0xFF, 0xFF, 0xFF, 0xFF, 0xFF, 0xFF, 0xFF, 0xFF, 0xFF, 0xFF, 0xFF, 0xFF, 0xFF, 0xFF, 0xFF, 0xFF,
0xFF, 0xFF, 0xFF, 0xFF, 0xFF, 0xFF, 0xFF, 0xFF, 0xFF, 0xFF, 0xFF, 0xFF, 0xFF, 0xFF, 0xFF, 0xFF,
0xFF, 0xFF, 0xFF, 0xFF, 0xFF, 0xFF, 0xFF, 0xFF, 0xFF, 0xFF, 0xFF, 0xFF, 0xFF, 0xC0, 0x03, 0xFF,
0xFF, 0xFF, 0xFF, 0xFF, 0xFF, 0xFF, 0xFF, 0xFF, 0xFF, 0xC0, 0x01, 0xFF, 0xFF, 0xFF, 0xFF, 0xFF,
0xFF, 0xFF, 0xFF, 0xFF, 0xFF, 0x80, 0x01, 0xFF, 0xFF, 0xFF, 0xFF, 0xFF, 0xFF, 0xFF, 0xFF, 0xFF,
0xFF, 0x80, 0x01, 0xFF, 0xFF, 0xFF, 0xFF, 0xFF, 0xFF, 0xFF, 0xFF, 0xFF, 0xFF, 0x80, 0x01, 0xFF,
0xFF, 0xFF, 0xFF, 0xFF, 0xFF, 0xFF, 0xFF, 0xFF, 0xFF, 0x80, 0x01, 0xFF, 0xFF, 0xFF, 0xFF, 0xFF,
0xFF, 0xFF, 0xFF, 0xFF, 0xFF, 0x80, 0x01, 0xFF, 0xFF, 0xFF, 0xFF, 0xFF, 0xFF, 0xFF, 0xFF, 0xFF,
0xFF, 0x80, 0x00, 0xFF, 0xFF, 0xFF, 0xFF, 0xFF, 0xFF, 0xFF, 0xFC, 0xFF, 0xFF, 0x00, 0x00, 0xFF,
0xFF, 0x3F, 0xFF, 0xFF, 0xFF, 0xFF, 0xFC, 0x3F, 0xFF, 0x00, 0x00, 0xFF, 0xFC, 0x3F, 0xFF, 0xFF,
0xFF, 0xFF, 0xF8, 0x1F, 0xFF, 0x00, 0x00, 0xFF, 0xF8, 0x1F, 0xFF, 0xFF, 0xFF, 0xFF, 0xF0, 0x03,
0xFF, 0x00, 0x00, 0xFF, 0xF0, 0x0F, 0xFF, 0xFF, 0xFF, 0xFF, 0xE0, 0x03, 0xF8, 0x00, 0x00, 0x1F,
0xC0, 0x03, 0xFF, 0xFF, 0xFF, 0xFF, 0xC0, 0x00, 0xE0, 0x00, 0x00, 0x03, 0x80, 0x01, 0xFF, 0xFF,
0xFF, 0xFF, 0x80, 0x00, 0x00, 0x00, 0x00, 0x00, 0x00, 0x01, 0xFF, 0xFF, 0xFF, 0xFF, 0x00, 0x00,
0x00, 0x00, 0x00, 0x00, 0x00, 0x00, 0xFF, 0xFF, 0xFF, 0xFE, 0x00, 0x00, 0x00, 0x00, 0x00, 0x00,
0x00, 0x00, 0x7F, 0xFF, 0xFF, 0xFF, 0x00, 0x00, 0x00, 0x00, 0x00, 0x00, 0x00, 0x00, 0x7F, 0xFF,
0xFF, 0xFE, 0x00, 0x00, 0x00, 0x00, 0x00, 0x00, 0x00, 0x00, 0xFF, 0xFF, 0xFF, 0xFF, 0x80, 0x00,
0x00, 0x00, 0x00, 0x00, 0x00, 0x01, 0xFF, 0xFF, 0xFF, 0xFF, 0xC0, 0x00, 0x00, 0x00, 0x00, 0x00,
0x00, 0x01, 0xFF, 0xFF, 0xFF, 0xFF, 0xC0, 0x00, 0x00, 0x00, 0x00, 0x00, 0x00, 0x03, 0xFF, 0xFF,
0xFF, 0xFF, 0xE0, 0x00, 0x00, 0x00, 0x00, 0x00, 0x00, 0x07, 0xFF, 0xFF, 0xFF, 0xFF, 0xF0, 0x00,
0x00, 0x00, 0x00, 0x00, 0x00, 0x07, 0xFF, 0xFF, 0xFF, 0xFF, 0xF0, 0x00, 0x00, 0x00, 0x00, 0x00,
0x00, 0x0F, 0xFF, 0xFF, 0xFF, 0xFF, 0xF8, 0x00, 0x00, 0x00, 0x00, 0x00, 0x00, 0x1F, 0xFF, 0xFF,
0xFF, 0xFF, 0xF8, 0x00, 0x00, 0x00, 0x00, 0x00, 0x00, 0x1F, 0xFF, 0xFF, 0xFF, 0xFF, 0xF8, 0x00,
0x00, 0x00, 0x00, 0x00, 0x00, 0x0F, 0xFF, 0xFF, 0xFF, 0xFF, 0xF0, 0x00, 0x00, 0x00, 0x00, 0x00,
0x00, 0x07, 0xFF, 0xFF, 0xFF, 0xFF, 0xE0, 0x00, 0x00, 0x00, 0x00, 0x00, 0x00, 0x07, 0xFF, 0xFF,
0xFF, 0xFF, 0xE0, 0x00, 0x00, 0x01, 0xC0, 0x00, 0x00, 0x07, 0xFF, 0xFF, 0xFF, 0xFF, 0xE0, 0x00,
0x00, 0x1F, 0xF8, 0x00, 0x00, 0x03, 0xFF, 0xFF, 0xFF, 0xFF, 0xC0, 0x00, 0x00, 0x3F, 0xFE, 0x00,
0x00, 0x03, 0xFF, 0xFF, 0xFF, 0xFF, 0x80, 0x00, 0x00, 0x7F, 0xFF, 0x00, 0x00, 0x00, 0xFF, 0xFF,
0xFF, 0xE0, 0x00, 0x00, 0x00, 0x7F, 0xFF, 0x00, 0x00, 0x00, 0x07, 0xFF, 0xFE, 0x00, 0x00, 0x00,
0x01, 0xFF, 0xFF, 0x80, 0x00, 0x00, 0x00, 0x7F, 0xFE, 0x00, 0x00, 0x00, 0x01, 0xFF, 0xFF, 0xC0,
0x00, 0x00, 0x00, 0x7F, 0xFE, 0x00, 0x00, 0x00, 0x03, 0xFF, 0xFF, 0xC0, 0x00, 0x00, 0x00, 0x7F,
0xFE, 0x00, 0x00, 0x00, 0x03, 0xFF, 0xFF, 0xC0, 0x00, 0x00, 0x00, 0x7F, 0xFE, 0x00, 0x00, 0x00,
0x03, 0xFF, 0xFF, 0xE0, 0x00, 0x00, 0x00, 0x7F, 0xFE, 0x00, 0x00, 0x00, 0x03, 0xFF, 0xFF, 0xE0,
0x00, 0x00, 0x00, 0x7F, 0xFE, 0x00, 0x00, 0x00, 0x07, 0xFF, 0xFF, 0xE0, 0x00, 0x00, 0x00, 0x7F,
0xFE, 0x00, 0x00, 0x00, 0x03, 0xFF, 0xFF, 0xE0, 0x00, 0x00, 0x00, 0x7F, 0xFE, 0x00, 0x00, 0x00,
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
};

static const unsigned char SeeedLogo[] PROGMEM = 
{
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

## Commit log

2016-09-02 initial version
    [TSOC_GROVEY_I2CHUB.brd, TSOC_GROVEY_I2CHUB.sch, TSOC_GROVEY_I2CHUB.skp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]
2016-10-01 update to Rev.1.1
    [TSOC_GROVEY_I2CHUB.csv, TSOC_GROVEY_I2CHUB_R2_0.ods]
2016-10-17 update BOM
    [TSOC_GROVEY_I2CHUB_R2_0.ods, TSOC_GROVEY_I2CHUB_seeed.csv]
2016-11-08 update to Rev2.1
    [TSOC_GROVEY_I2CHUB_R2_1.brd, TSOC_GROVEY_I2CHUB_R2_1.sch, TSOC_GROVEY_I2CHUB_bom_R2_1_seeed.csv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]
2017-01-16 update documetation
    [TSOC_GROVEY_I2CHUB_pinout.ods]

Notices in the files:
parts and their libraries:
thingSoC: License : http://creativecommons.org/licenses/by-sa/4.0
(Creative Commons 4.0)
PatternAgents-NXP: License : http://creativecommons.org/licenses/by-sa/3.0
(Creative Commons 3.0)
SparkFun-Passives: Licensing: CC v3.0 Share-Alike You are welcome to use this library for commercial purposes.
